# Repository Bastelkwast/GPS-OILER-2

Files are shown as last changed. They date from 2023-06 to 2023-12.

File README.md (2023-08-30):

# GPS-Oiler-2

Neue Firmware 2.8!!

Änderungen:

- Bug mit der Steuerung des Ölsymbols beseitigt.

- Es kann gewählt (im Interface) werden, ob und wie viele Pumpimpulse zu beginn der Fahrt erzeugt werden (Initial Ölung).
  Die Änderung ist erst nach einem Neustart des Oilers übernommen.

Ich bin gerade dabei die Seite umzubauen damit sie übersichtlicher wird.
Dafür benötige ich noch etwas Zeit.
Ich bitte um Verständnis.

## [Beschreibung](docs/Beschreibung/README.md)

## [Nachbau](docs/Nachbau/README.md)

## [Vorkenntnisse](docs/Vorkenntnisse/README.md)

## [Firmware Version 2.7](docs/Firmware_2.7/README.md)

## [Mainboard Rev. 5](docs/Mainboard_Rev5/README.md)

## [Bin Datei aufspielen](docs/Firmware_BIN/README.md)

## [Einbauvorschlag](docs/Tracer_900GT/README.md)

Bei Fragen einfach eine Mail an mich: GPS-Kettenoiler@web.de

Ich werde Versuchen sie zeitnah zu Beantworten.

Über eine Information mit euren Erfahrungen würde ich mich sehr freuen.

Nur so kann ich den Oiler verbessern!

Wenn ihr mir Bilder oder Anregungen von eurem Einbau zukommen lasst, und ihr es wünscht, werde ich sie auch anderen zur Verfügung stellen.

Vielleicht wird es dadurch ja noch interessanter für den ein oder anderen.

!! Der Nachbau ist ohne meiner ausdrücklichen Genehmigung nur für Private und nicht für Kommerzielle Zwecke erlaubt !!

!!Der Nachbau und Einbau des Kettenöler und seiner Bauteile erfolgt auf eigenes Risiko und Verantwortung. Ich übernehme keine Haftung!!

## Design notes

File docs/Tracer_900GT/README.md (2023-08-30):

# Einbau in einer Tracer 900 GT

## [Injector](Injector/README.md)

Die Dateien für die Gedruckten und Gefrästen Teile findet ihr im Ordner docs/Tracer_900GT/STL-Dateien

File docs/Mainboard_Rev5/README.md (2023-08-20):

# Mainboard Rev.5

## [Schaltplan](PDF/SCHALTPLAN.pdf)

## [LAYOUT](PDF/LAYOUT.pdf)

## [Bestückungsplan](PDF/BESTUECKUNGSPLAN.pdf)

Der Nachbau und Einbau des Kettenöler und seiner Bauteile erfolgt auf eigenes Risiko und Verantwortung. Ich übernehme keine Haftung.

Hier beschreibe ich den Bau des Mainboard Rev..

## Benötigte Bauteile

### Widerstände

|Bezeichnung |Beschreibung |
|---|---|
|R1 |100Ω |
|R2,R5 |10KΩ |
|R3 |2,7KΩ |
|R4 |100kΩ |
R6,R7,R8            |1KΩ                        |

### Diode

|Bezeichnung |Beschreibung |
|---|---|
|D1 |1N4007 |

### Kondensatoren

|Bezeichnung |Beschreibung |
|---|---|
|C1 |470µF/16V  RM 5mm  Elko |
|C2 |1500µF/6,3V RM 3,5  Elko |

### Transistoren

|Bezeichnung |Beschreibung |
|---|---|
|Q1 |BUZ11A |
|Q2 |BS170 |

### Sonstiges

|Bezeichnung |Beschreibung |
|---|---|
|DS R-78E50-05 |5V DC/DC Wandler |
|S1 |Kurzhubtaster 9302 |
|Controller |Wemos D1 Mini |
|GPS Modul |Neo-6M |
|OLED Display |SSD1306 Weiss I2C |
|EEPROM |24LC256-I/P |
|IC Sockel |GS 8 |
|Gummidurchführung  |5x	KDF4 |
|Klemmleiste 4fach  |AKL 059-4  Für das OLED |
|Kunststoffgehäuse  |SP 2062 SW |
|Klemmleiste 10fach |AKL 101-10 |
|Dosierpumpe |Webasto oder ähnlich |
|Kleine Schrauben |4x (2,2x4,5mm) |
|Schraube |3mm mit Mutter |
|Fotoplatine |FPE1 160X100 |

Und alles was zum Herstellen einer Leiterplatte benötigt wird.
Ich habe zum Verbinden des GPS-Modul und dem OLED mit dem Mainboard ein USB Kabel verwendet. Das war günstiger.

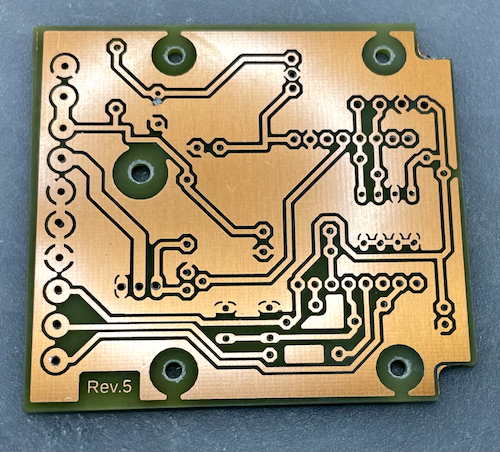
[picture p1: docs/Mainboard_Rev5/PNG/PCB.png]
PCB


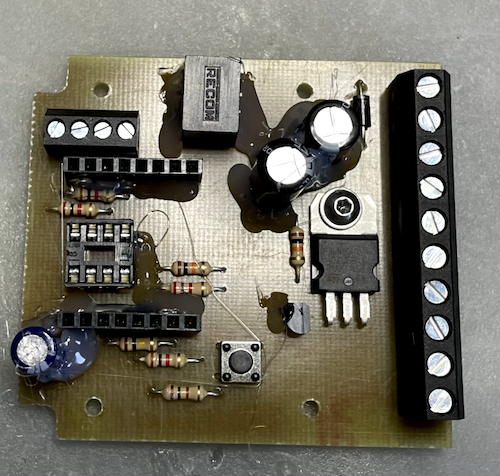
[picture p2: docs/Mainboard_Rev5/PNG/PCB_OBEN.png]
PCB OBEN


Und hier mit aufgesetztem WEMOS und DC/DC Wandler. Hatte Probleme mit der Wärmeentwicklung.

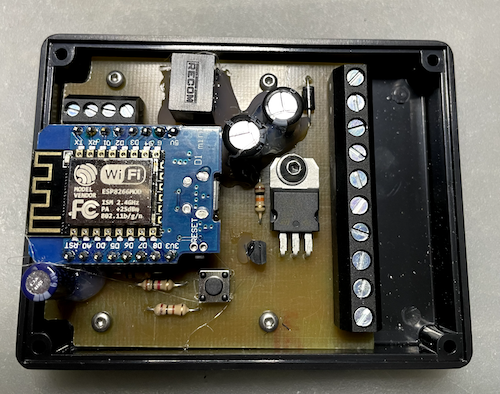
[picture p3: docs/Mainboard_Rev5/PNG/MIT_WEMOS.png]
PCB MIT WEMOS

Der Anschluss oben links ist vom OLED.

Der Taster ist zum zurücksetzen der WIFI Einstellung für den Fall das man sein WIFI Passwort vergessen haben sollte und nicht mehr rankommt.

## Anschlüsse

Masse       = Masse oder Minuspol

Klemme 15   = Zündung( Bei meiner Tracer der Stecker der Sitzbankheizung)

Pumpe       = Plus der Dosierpumpe

Pumpe       =   Minus der Dosierpumpe

3xGND       = GND für GPS,Regensensor.

VCC-2       = 3,3V für den GPS Modul

GPS-RX      = TX des GPS-Modul

Sensor      = Anschluss des Regensensor

## Vor der ersten Inbetriebnahme

Vor der ersten Inbetriebnahme unbedingt noch mal alles kontrollieren ob da alles richtig eingebaut wurde und keine Kurzschlüsse oder Unterbrechungen mehr vorhanden sind.

Wenn das erste mal Spannung angelegt wird, habe ich immer den WEMOS,OLED und das EEPROM abgezogen und erst einmal die Betriebsspannung 5V am WEMOS überprüft um zu sehen das der DC/DC Wandler auch seine 5V richtig ausgibt.

Wenn der Oiler das erste mal in Betrieb genommen wird, erkennt er daß das EEPROM noch unbeschrieben ist und beschreibt es dann mit den Werkseinstellungen automatisch.

Jetzt sollte alles funktionieren.

Es sollte jetzt etwas auf dem Display zu sehen ein. Wenn ja hat alles geklappt.

Glückwunsch!

Wenn nicht, geht die Fehlersuche los.

Sind die 3,3V am WEMOS vorhanden. Wenn nicht ist der WEMOS defekt.

Ist die 3,3V vorhanden, ist WIFI vorhanden. Wenn nicht, wurde die Firmware richtig aufgespielt?

Ist das OLED richtig angeschlossen?

Ist das OLED okay, ist GPS Empfang vorhanden? (kann bis 3 Min dauern. Dazu an einen Ort gehen wo auch Satellitenempfang möglich ist).

## Viel Erfolg beim Nachbau!

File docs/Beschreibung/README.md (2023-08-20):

# GPS-Oiler-2

## Mein GPS-OILER-2
Ich hatte mir ein neues Motorrad gekauft und wollte mir einen Mikrocontroller gesteuerten Kettenöler einbauen. 

Da ich ein Bastler bin und mit dem Arduino auch schon einiges gemacht hatte wollte ich mir einen eigenen Kettenöler bauen.

Da ich nicht an das Tachosignal gehen wollte musste ich mir etwas anderes überlegen. Einen Magneten irgendwo anzukleben und einen Reed Kontakt zu verwenden fand ich auch nicht so elegant. Aus diesem Grund habe ich mich für ein GPS Modul entschieden.

Ich wollte das ganze recht universell halten und habe das Mainboard und das GPS-Modul von einander getrennt. So kann man das Mainboard an einem Platz installieren wo kein Sat-Empfang möglich ist.

Um zu sehen ob alles vernünftig funktioniert habe ich dem Kettenöler ein kleines 0,96“ OLED Display spendiert das mir alle notwendigen Informationen anzeigt wie Geschwindigkeit, Füllstand des Öltank, bereits gefahrene km seit dem befüllen des Öltank, Richtung, Anzahl der empfangenen Satelliten, ob er gerade ölt, ob der Regenmodus aktiviert ist.

Das die Kette auch bei Regen entsprechend geölt wird habe ich einen Regenmodus eingebaut. Für die Regenerkennung benutze ich einen Regensensor der sich unter dem Bugspoiler befindet. 
Eine Individuelle Anpassung der Schwellwerte des Sensor ist im WEB Interface möglich.

Als Ölpumpe benutzte ich den Nachbau einer Webasto Dosierpumpe die 50 Pumpimpulse / ml benötigt. Es kann auch eine andere Dosierpumpe verwendet werden, die Parameter können leicht angepasst werden.

Damit ich den Kettenöler auch bedienen kann habe ich mich für den ESP 8266 Wemos entschieden. Der hat eine höhere Taktfrequenz als ein Arduino und ein WIFI Modul ist auch schon on Board. Somit habe ich für die Bedienung ein Web Interface gebaut und kann mit jedem WIFI fähigen Gerät sämtliche Einstellungen am Kettenöler vornehmen und Informationen abrufen die nicht auf dem OLED angezeigt werden. Dadurch bin ich nicht an Android oder Apple gebunden und benötige auch keine Apps dafür.

Das WIFI wird nach einer vorgegebenen Zeit abgeschaltet. Danach ist das WEB Interface bis zum nächsten Einschalten für niemanden mehr erreichbar.

Da der Wemos keinen eingebauten EEPROM besitzt kam auch ein externer EEPROM für die Speicherung aller Einstellungen und Werte zum Einsatz.

Um das Öl auf die Kette zu bekommen und ich so wenig wie möglich vom Kettenöler sehen wollte bin ich an das vordere Kettenrad gegangen und habe dafür einen Dual Injektor gebaut.

Für den Fall das der GPS Empfänger ausfällt habe ich einen Notbetrieb eingebaut der nach dem Einschalten nach einer eingestellten Zeit automatisch Aktiviert wird und eine vorgegebene Geschwindigkeit annimmt bis wieder Satellitenempfang vorhanden ist. 

Sollte der Satellitenempfang unterbrochen werden wie z.B. durch einen Tunnel, wird die letzte Geschwindigkeit so lange beibehalten bis wieder Satellitenempfang vorhanden ist.

Da der GPS-Kettenöler über Zündung (Klemme15) mit Spannung versorgt wird, kann auch keine Fehlfunktion eine Entladung der Batterie verursachen.

Ich habe zwei Startbildschirme eingebaut.
In 1. Startbildschirm wird mir die SSID des Kettenöler und die IP Adresse angezeigt (nachdem ich sie mal vergessen hatte ;-) ).
Im 2. die Version des Kettenöler und die Firmware Version. Die Anzeigezeit lässt sich im Web Interface anpassen.

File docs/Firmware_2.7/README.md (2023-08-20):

# Firmware Version 2.7

Hier wird der Kettenoiler mit der Firmware 2.7 Beschrieben.

Ich habe zwei Startbildschirme eingebaut die nach dem Einschalten angezeigt werden.

In 1. Startbildschirm wird mir die SSID des Kettenöler und die IP Adresse angezeigt (nachdem ich sie mal vergessen hatte ;-).

Im 2. die Version des Kettenöler und die Firmware Version.

Die Anzeigezeit lässt sich im Web Interface anpassen.

## Das OLED Display

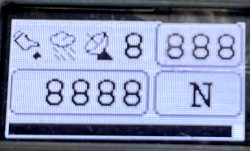
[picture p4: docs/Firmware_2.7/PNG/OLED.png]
OLED


### Erklärung obere Reihe von links nach rechts

-Die Kette wird gerade geölt.

-Regenmodus ist Aktiv.

-Satellitenempfang vorhanden.

-Anzahl der empfangenen Satelliten. Wenn die Anzahl der empfangenen Satelliten die Anzahl 9 übersteigt wird die Zehnerstelle anstelle des Satelliten Symbol angezeigt.

-Die ermittelte Geschwindigkeit.

### Untere Reihe•

-Gefahrene km seit dem letzten auffüllen.

-Die Himmelsrichtung in die man fährt

-Ganz unten befindet sich ein Balken der den berechneten Füllstand des Öltanks anzeigt.

### Browser

Um mit einem Browser das Web Interface nutzen zu können muss man als erstes das WIFI des Kettenölers in den Einstellungen des WIFI fähigen Gerät auswählen.

Anschließend gibt man im Browser die IP Adresse „192.168.4.1“ ein.

Jetzt sollte das Interface wie unten beschrieben zu sehen sein.

### Das Web Interface

Mit Hilfe des Web Interface kann man die Einstellungen des Kettenölers anzeigen lassen und wenn nötig anpassen.

## Startseite des Web Interface

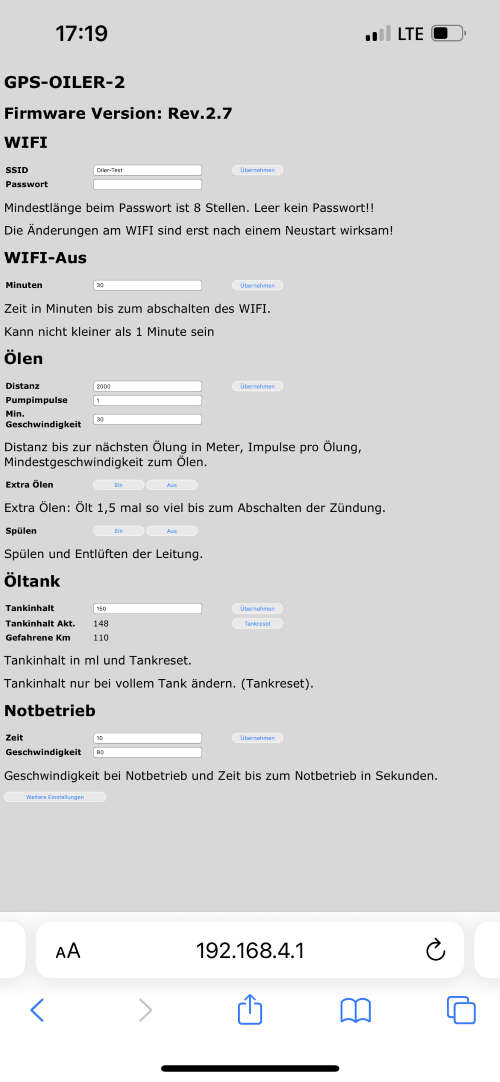
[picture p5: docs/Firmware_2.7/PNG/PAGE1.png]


### Wifi

Einstellung der SSID Kennung Einstellung des WIFI Passwort.

Wenn das Feld „Passwort“ keinen Eintrag hat, wird kein Passwort abgefragt.

### WIFI- Aus

Die Zeit in Minuten nach dem Einschalten und der letzten Eingabe über das Web Interface bis WIFI automatisch abgeschaltet wird.

### Ölen

Die Distanz zwischen den einzelnen Ölungen. Anzahl der Pumpimpulse pro Ölung.
Mindestgeschwindigkeit unter der das Ölen verhindert wird.

### Extra Ölen

Hier kann ich extra Ölen aktivieren. Durch das aktivieren wird der Abstand der einzelnen Ölungen um den Faktor 1,5 reduziert für den Fall das man z.b. auf Sandwegen unterwegs sein sollte. Das extra Ölen wird mit dem abschalten der Zündung automatisch deaktiviert.
Spülen
Der Kettenöler pumpt so lange bis Spülen wieder abgewählt oder die Zündung abgeschaltet wird.

### Öltank

Tankinhalt in ml.Aktueller Tankinhalt in ml.Gefahrene km seit „Übernehmen“ oder „Tankreset“.

### Notbetrieb

Wenn kein Sat-Empfang vorhanden ist, Zeit in Sekunden bis der Notbetrieb aktiviert wird. Bleibt so lange aktiv bis wieder Satellitenempfang vorhanden ist.
Angenommene Geschwindigkeit für den Notbetrieb.

### Weitere Einstellungen ( zweite Seite des Web Interface )

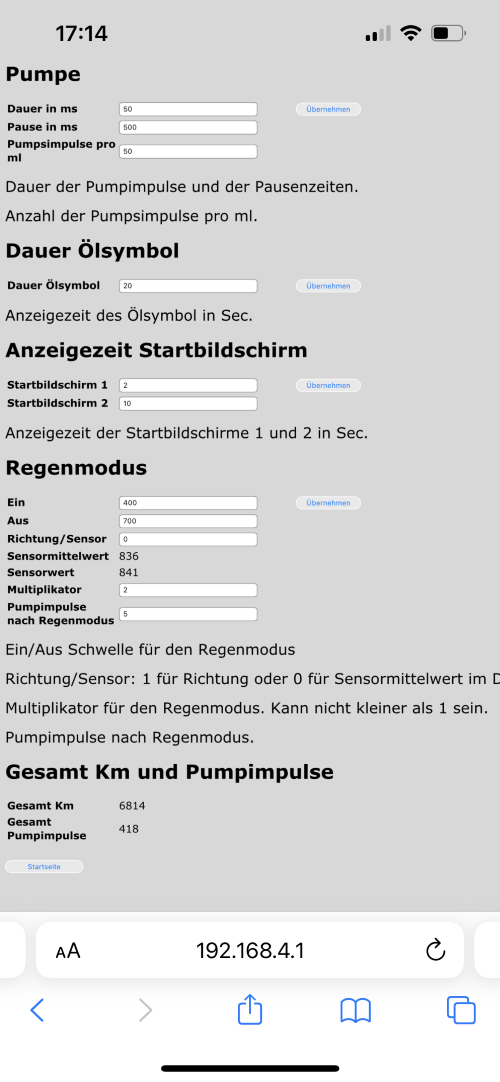
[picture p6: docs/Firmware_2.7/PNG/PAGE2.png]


### Pumpe

Dauer in Millisekunden wie lange die Pumpe mit Spannung versorgt wird.
Dauer in Millisekunden wie lange die Pause zwischen zwei Pumpimpulsen mindestens sein soll.
Anzahl der Pumpimpulse die für 1 ml benötigt werden.

### Dauer Ölsymbol

Zeit in Sekunden wie lange das Ölen Symbol im OLED Display angezeigt wird.

### Anzeigezeit Startbildschirm

Zeit in Sekunden wie lange der Startbildschirm 1 nach dem Einschalten angezeigt werden soll.
Zeit in Sekunden wie lange der Startbildschirm 2 nach dem Einschalten angezeigt werden soll.

### Regenmodus

#### Ein

Schwellwert bei dem der Regenmodus aktiviert werden soll.

#### Aus

Schwellwert bei dem der Regenmodus wieder deaktiviert werden soll.
Der Schwellwerte für das Aktivieren des Regenmodus muss niedriger als der Schwellwert für das Deaktivieren des Regenmodus sein.

#### Richtung/Sensor

Hier kann ich wählen was ich im OLED angezeigt haben möchte. Entweder die Richtung in die ich gerade fahre oder der Wert des Regensensor. Das habe ich eingebaut damit ich einen besseren überblick von Regensensor haben kann.

#### Sensormittelwert

Hier wird der errechnete Sensormittelwert angezeigt.

#### Sensorwert

Aktueller Sensorwert.

#### Multiplikator

Multiplikator wie viel mehr bei Regen geölt werden soll. Er kann nicht kleiner als 1 eingestellt werden.

#### Pumpimpulse bei Regenmodus

Anzahl der Pumpimpulse nach dem Regenmodus. Dadurch soll das Öl das durch den Regen abgespült wurde wieder auf die Kette gebracht werden.

#### Gesamt Km und Pumpimpulse

Gesamt km

Hier werden die km angezeigt die insgesamt mit dem Kettenöler gefahren wurden.

Gesamt Pumpimpulse

Hier werden die Pumpimpulse angezeigt die insgesamt mit dem Kettenöler gepumpt wurden.

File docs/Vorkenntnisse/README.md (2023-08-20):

## Vorkenntnisse

Es sind schon etwas Kenntnisse erforderlich um diesen Kettenöler nachzubauen.

Man sollte wissen was ein Widerstand ist und welche Wert er hat. 

Was ein Kondensator, Transistor usw. ist.

Man sollte sich auch schon mal mit dem Arduino beschäftigt haben und wissen was ein WEMOS ist, damit man sich mit der Arduino IDE (Programmier Tool) schon etwas auskennt.

Ein 12V Netzteil ist auch ganz nett um schon mal den Probelauf machen zu können. 

Löten sollte auch kein Problem darstellen.

Da die Leiterplatte selbst hergestellt wird, sollte man da auch schon Erfahrung gesammelt haben.

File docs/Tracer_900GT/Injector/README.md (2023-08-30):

# Injector

## Der Injektor an meiner Tracer 900 GT

### !!Der Nachbau und Einbau des Injektor und seiner Bauteile erfolgt auf eigenes Risiko und Verantwortung.

### Ich übernehme keine Haftung

Da ich so wenig wie möglich vom Kettenöler sehen wollte habe ich mich dafür entschieden den Injektor an das vordere Kettenrad zu setzen.

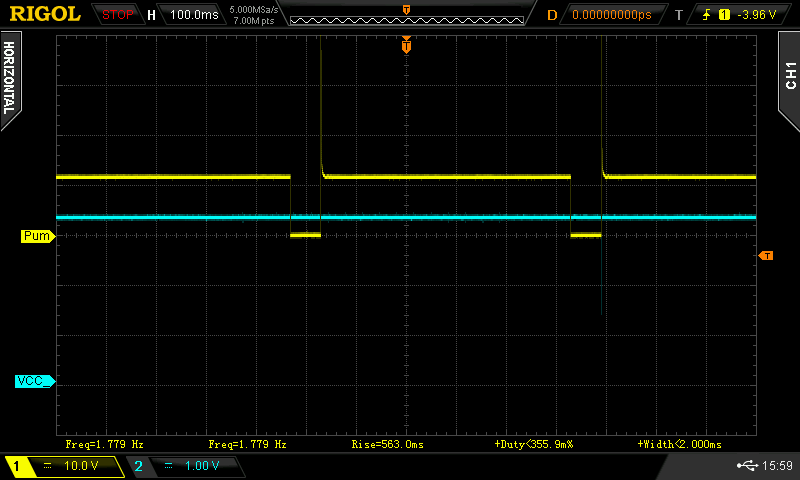
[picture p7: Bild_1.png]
Bild_1


## Das Halteblech für den Injector

Das Blech habe ich mit Hilfe einer CNC Fräse hergestellt.

Das Halteblech habe ich auf der Kettenseite etwas abgeschrägt damit die Kette auch wirklich nichts hat um daran hängen zu bleiben.

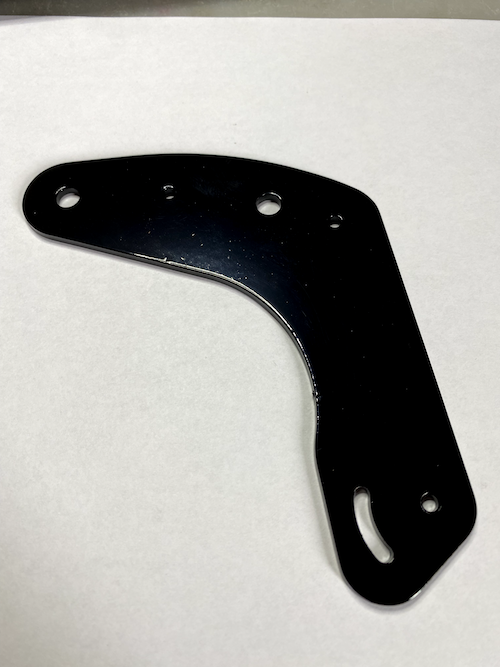
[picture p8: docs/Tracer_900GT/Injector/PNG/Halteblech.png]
Halteblech


Hier sind die Haltenasen die ich mit einem 3D Drucker gedruckt habe

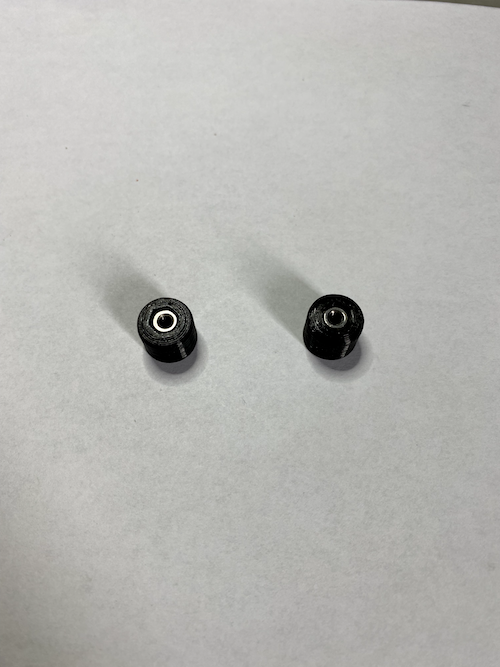
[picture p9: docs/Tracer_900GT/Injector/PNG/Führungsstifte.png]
Führungsstifte


Blech mit Haltenasen

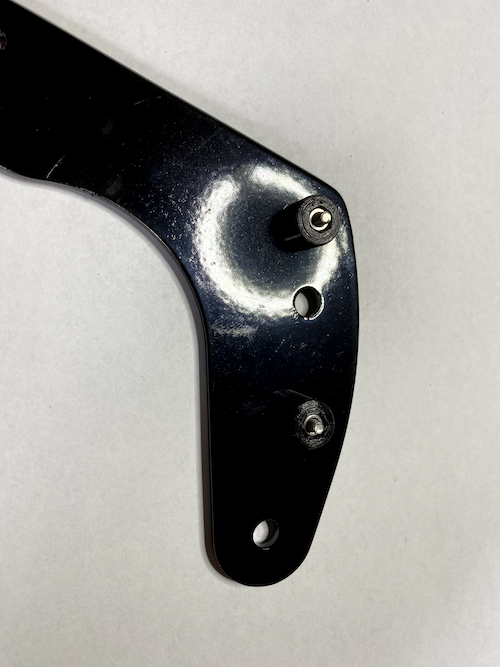
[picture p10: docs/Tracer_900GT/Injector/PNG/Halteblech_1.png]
Halteblech_1


Kettenführung

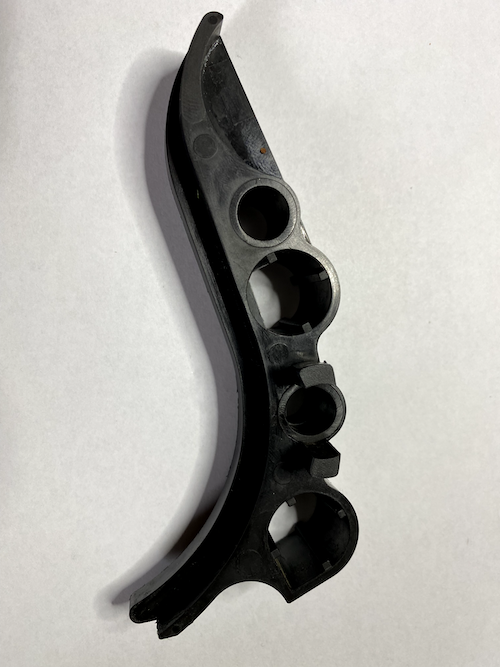
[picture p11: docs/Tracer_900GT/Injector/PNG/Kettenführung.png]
Kettenführung


Blech mit Kettenführung

Hier sind die beiden Führungsstifte und die Kettenführung mit dem Halteblech aus 3mm  Aluminium miteinander verbunden.
Dadurch wird später das ganze erst eimal in Position gehalten bis die Abdeckung das ganze zusammen hält.

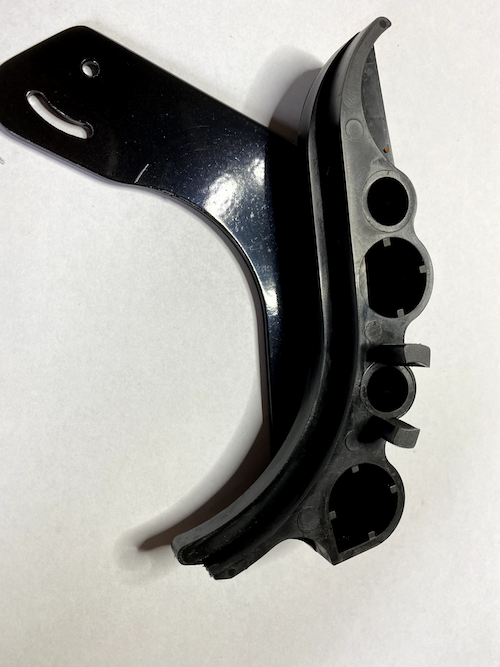
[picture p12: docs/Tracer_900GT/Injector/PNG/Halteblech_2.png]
Halteblech_2


Injector

Der aus PETG gedruckte Dual Injektor.

In den Injektorblock habe ich zwei Stückchen Silikonschlauch eingesetzt. Da hinein kommen dann die Röhrchen die dadurch im Block gehalten werden und das ganze schön Abgedichten.

Die Röhrchen habe ich aus dem Modellbau Zubehör (Bowdenzug).

Für den Schlauchanschluss dient ein stück Messingrohr.

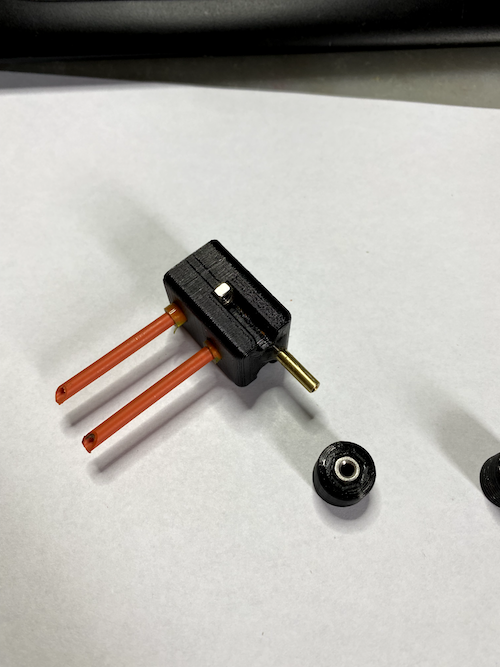
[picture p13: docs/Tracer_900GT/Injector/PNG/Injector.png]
Injector


Blech mit Injector

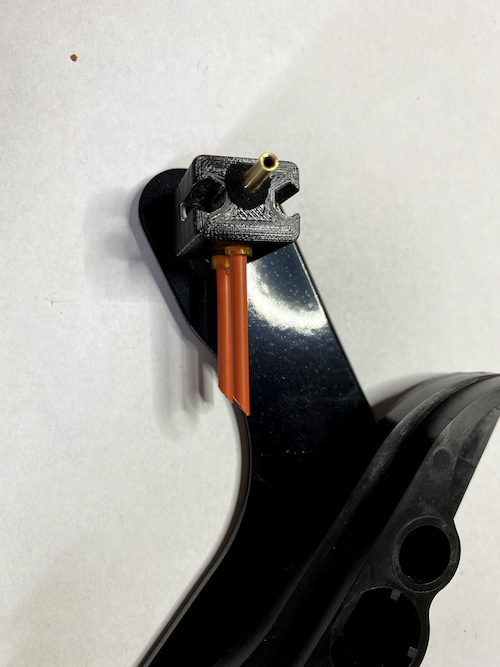
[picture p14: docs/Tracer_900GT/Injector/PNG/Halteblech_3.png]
Halteblech_3


Halteblech mit Injector am Motorrad angesetzt

Durch die Langlöcher kann der Injector optimal justiert werden.

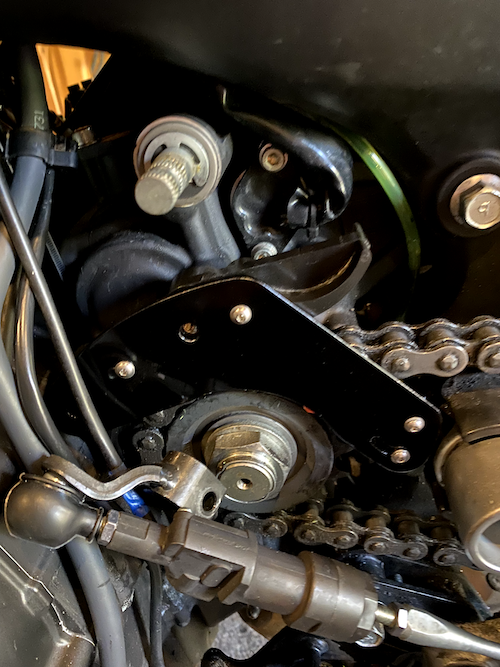
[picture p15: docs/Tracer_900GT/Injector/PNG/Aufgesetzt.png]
Aufgestetzt


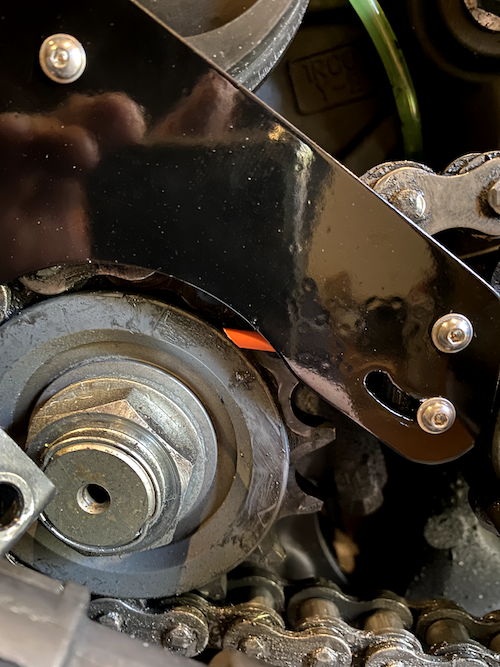
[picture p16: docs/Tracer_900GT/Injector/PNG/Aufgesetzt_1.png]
Aufgesetzt_1


Mit der Änderung der Kunststoffröhrchen wird das Öl besser auf die Kette übertragen.

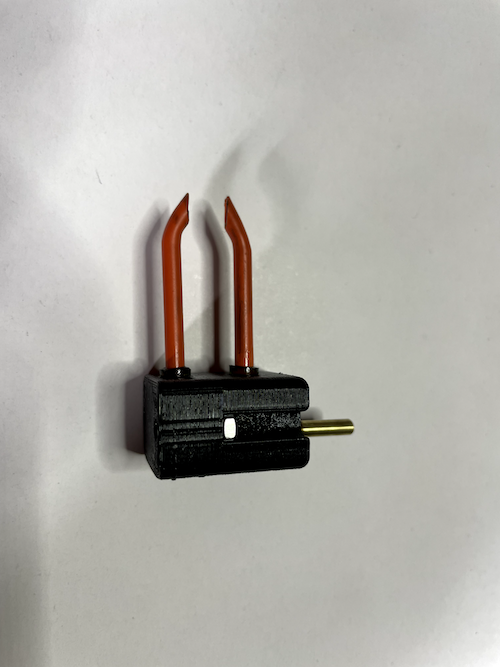
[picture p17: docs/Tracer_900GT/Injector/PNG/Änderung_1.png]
Änderung_1


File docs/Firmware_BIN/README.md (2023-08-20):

# BIN Datei aufspielen

Nicht jeder kennt sich mit VSC aus.

Deshalb habe ich nach einer anderen Möglichkeit gesucht die Firmware auf den WEMOS aufzuspielen.

In diesem Video erklärt Fabsenet sehr Verständlich wie man die BIN Datei (Firmware) auf den Wemos bekommen kann.

Nochmal vielen Dank für das super Video.

link: www.youtube.com/watch?v=TrDgyIsYsx4

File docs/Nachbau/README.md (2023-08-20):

## Nachbau

Ich habe vor hier alles was für einen erfolgreichen Nachbau notwendig ist zur Verfügung zu stellen.

Somit befindet sich hier:

- der Kompilierte Code sowie eine Anleitung die es ermöglichen soll den Wemos zu beschreiben.
- Schaltplan
- Das Layout der Leiterplatte.
- Bestückungsplan.
- Beschreibungen für das Mainboard, GPS-Empfänger, OLED Display, Injektor usw.
- stl Dateien für den 3D Drucker, um die Gehäuse und Halterungen die ich entworfen hatte,

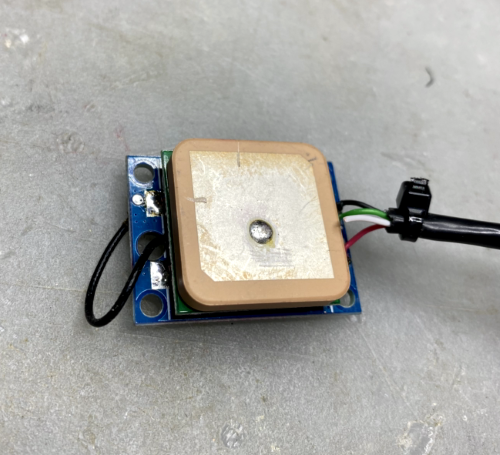
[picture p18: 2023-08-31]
docs/Tracer_900GT/PNG/GPS_3.png

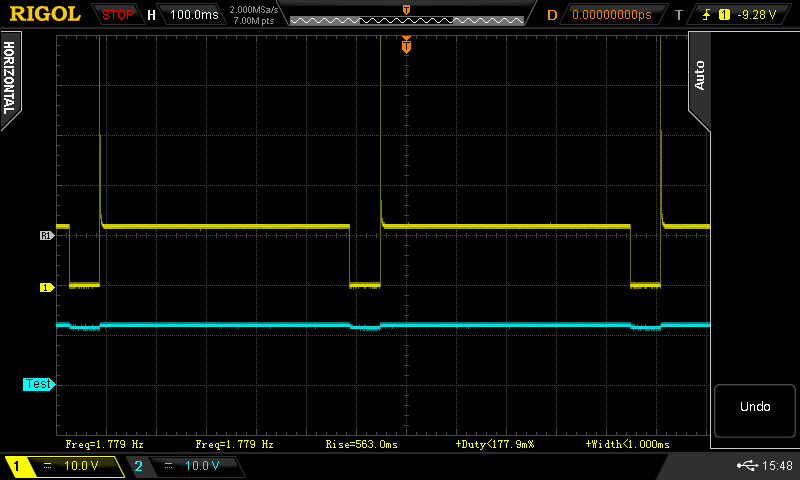
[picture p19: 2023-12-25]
DS2_20230811154808.png

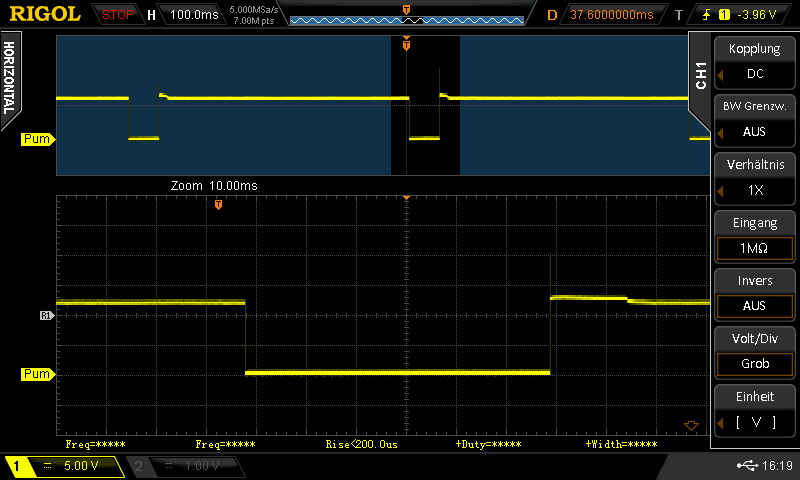
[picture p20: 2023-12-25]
DS2_20230811161950.png

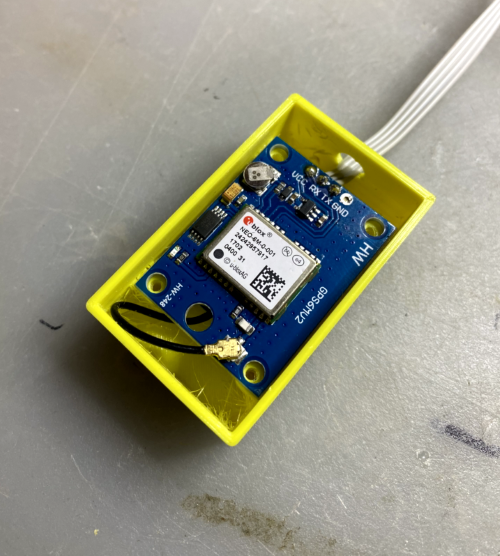
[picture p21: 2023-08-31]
docs/Tracer_900GT/PNG/GPS_2.png

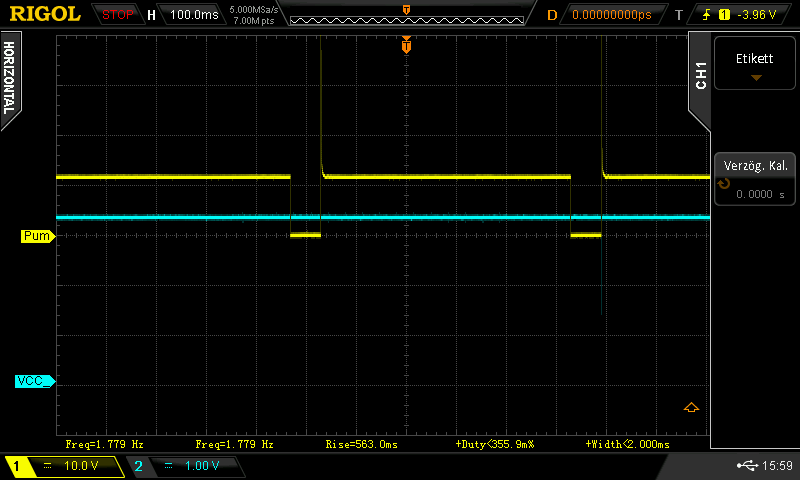
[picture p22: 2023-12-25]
DS2_20230811155905.png

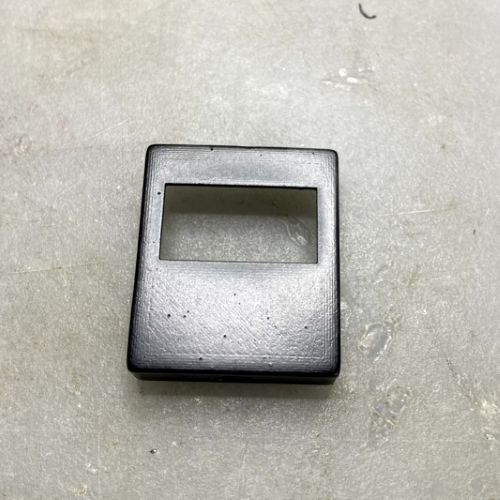
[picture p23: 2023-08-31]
docs/Tracer_900GT/PNG/OLED_Gehäuse.png

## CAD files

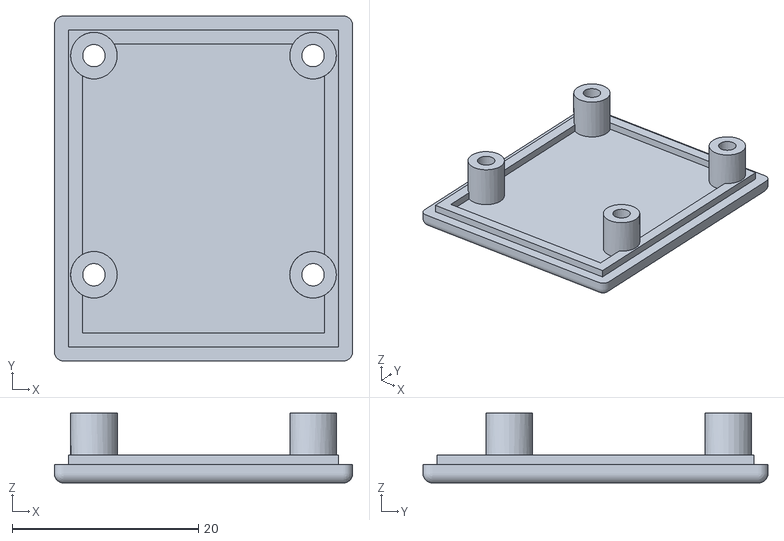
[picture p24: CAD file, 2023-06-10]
docs/Tracer_900GT/STL-Dateien/Display Tracer 900/OLED-Gehaeuse-Deckel.stl
32.0 x 37.0 x 7.50

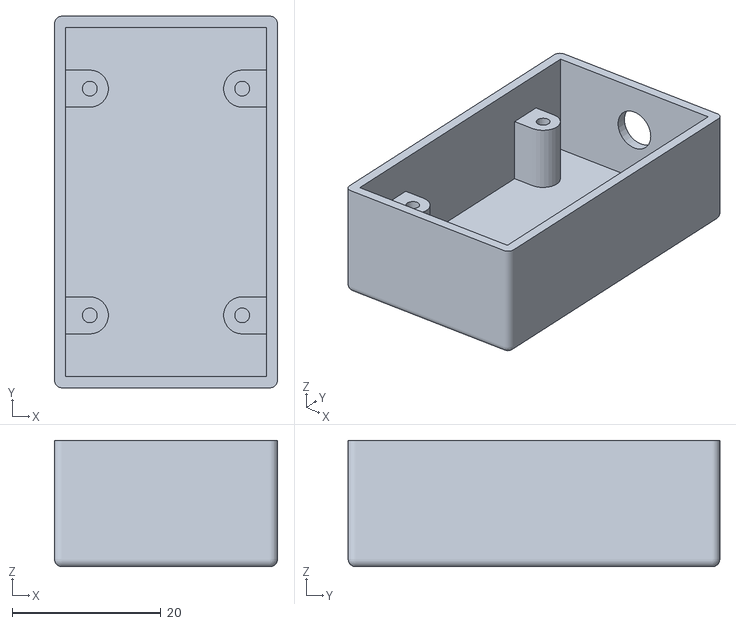
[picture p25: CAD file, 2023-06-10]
docs/Tracer_900GT/STL-Dateien/GPS/GPS-Gehaeuse.stl
30.0 x 50.0 x 17.0

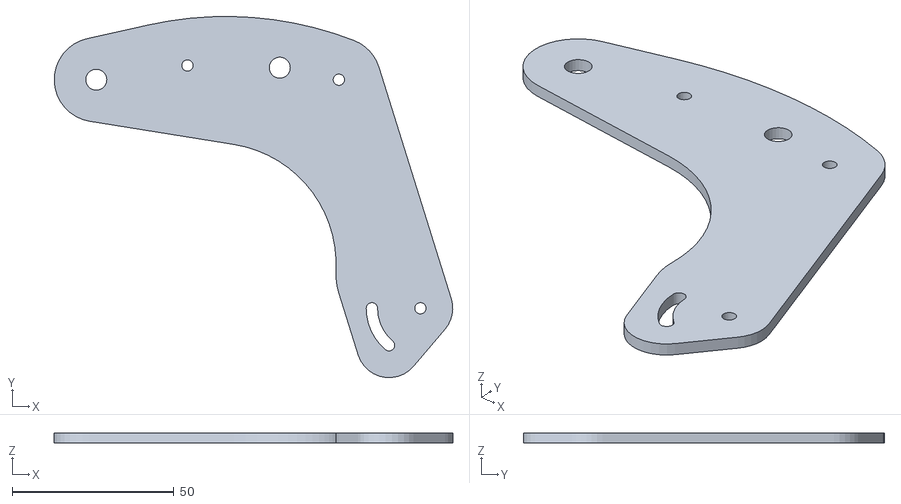
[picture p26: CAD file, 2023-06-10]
docs/Tracer_900GT/STL-Dateien/Injektor Vorne Tracer 900/Träger_Injektor_Vorne.stl
123.2 x 111.6 x 3.00

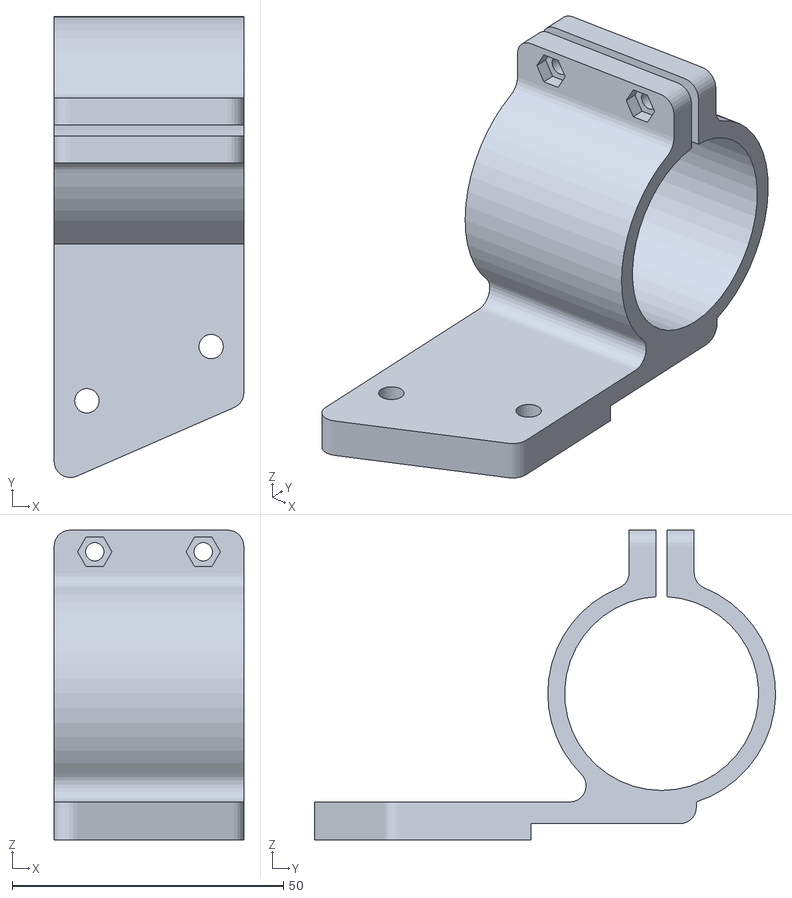
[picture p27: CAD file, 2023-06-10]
docs/Tracer_900GT/STL-Dateien/Pumpe Tracer 900/Halter Pumpe Links.stl
35.0 x 85.0 x 57.1

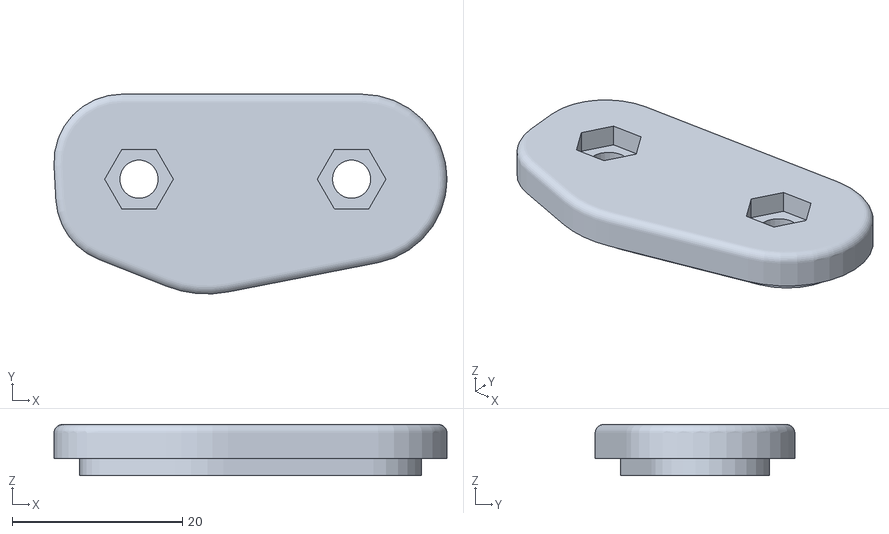
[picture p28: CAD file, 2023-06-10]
docs/Tracer_900GT/STL-Dateien/Tank Tracer 900/Lager_Rechts.stl
46.2 x 23.5 x 6.00

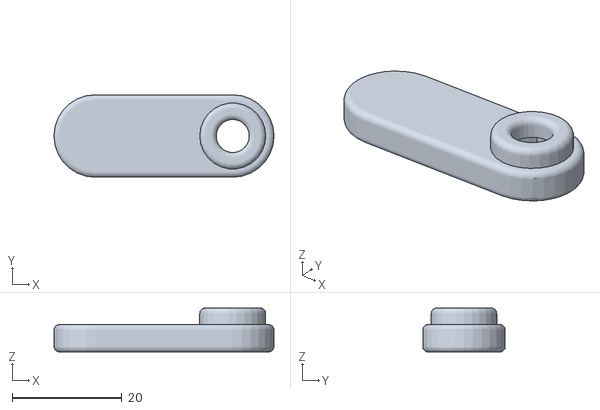
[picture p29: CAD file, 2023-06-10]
docs/Tracer_900GT/STL-Dateien/Display Tracer 900/Montierhilfe Rev.2.stl
40.0 x 15.0 x 8.00

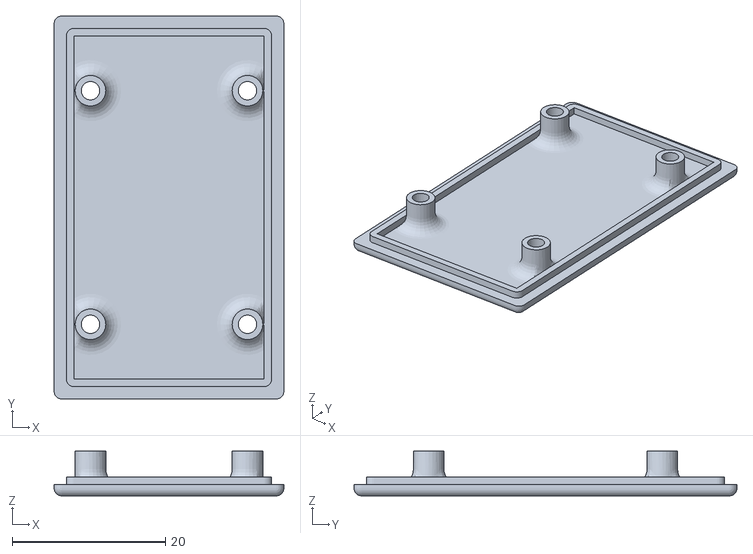
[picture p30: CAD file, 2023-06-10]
docs/Tracer_900GT/STL-Dateien/GPS/GPS-Gehaeuse_Deckel.stl
30.0 x 50.0 x 5.85

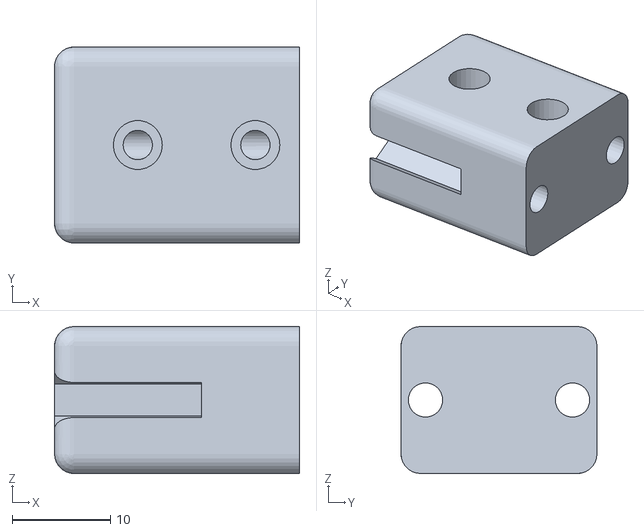
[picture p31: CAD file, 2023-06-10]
docs/Tracer_900GT/STL-Dateien/Injektor Vorne Tracer 900/Injektorblock_Vorne.stl
25.0 x 20.0 x 15.0

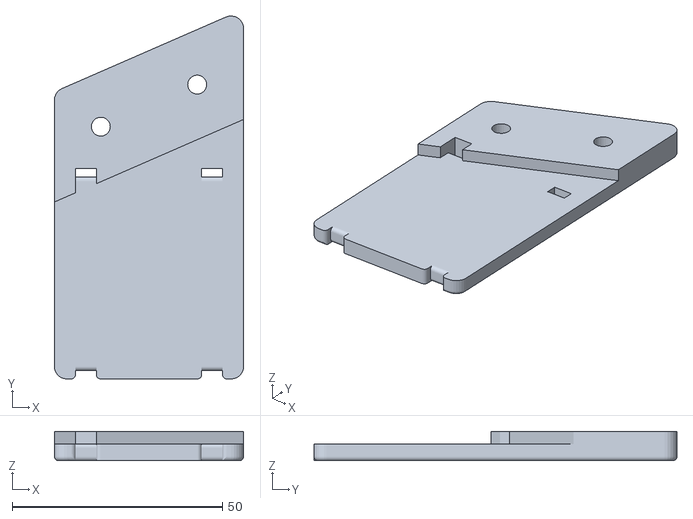
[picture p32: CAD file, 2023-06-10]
docs/Tracer_900GT/STL-Dateien/Tank Tracer 900/Halter Tank Rechts.stl
45.0 x 86.3 x 7.00

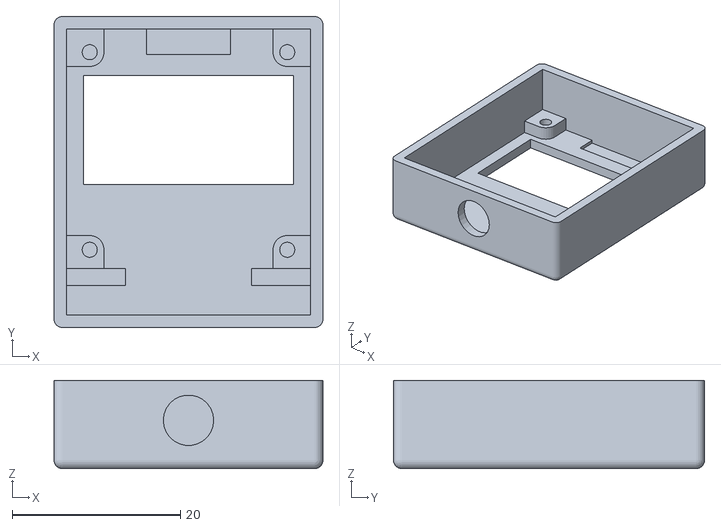
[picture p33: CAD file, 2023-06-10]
docs/Tracer_900GT/STL-Dateien/Display Tracer 900/OLED-Gehaeuse.stl
32.0 x 37.0 x 10.5

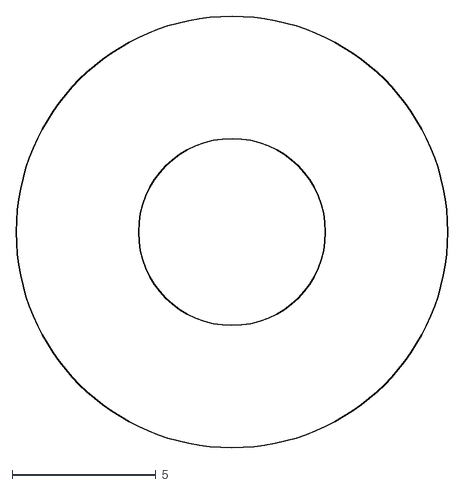
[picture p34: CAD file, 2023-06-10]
docs/Tracer_900GT/STL-Dateien/Injektor Vorne Tracer 900/Distanzscheibe_unten.dxf
15.0 x 15.0

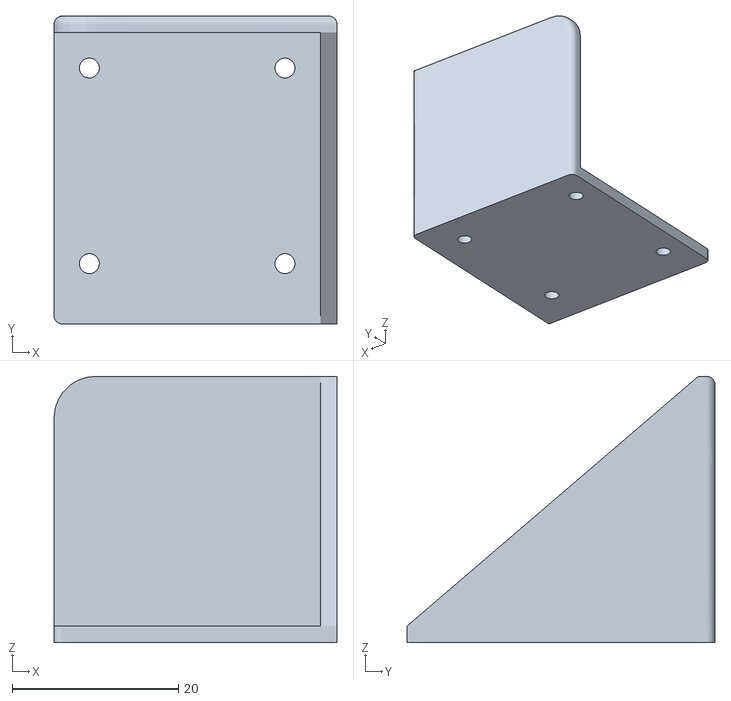
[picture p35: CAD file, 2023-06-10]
docs/Tracer_900GT/STL-Dateien/Display Tracer 900/Sonnenblende_Display.stl
34.0 x 37.0 x 32.0

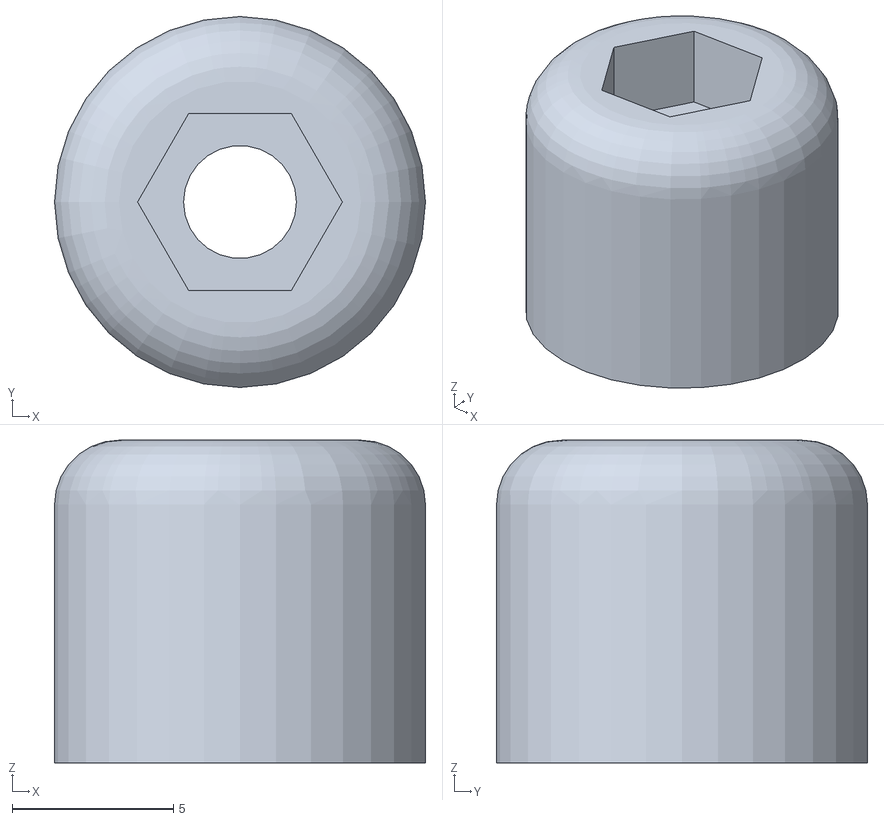
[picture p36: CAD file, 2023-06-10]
docs/Tracer_900GT/STL-Dateien/Injektor Vorne Tracer 900/Träger_Injektor_Vorne_Führungsstift.stl
11.5 x 11.5 x 10.0

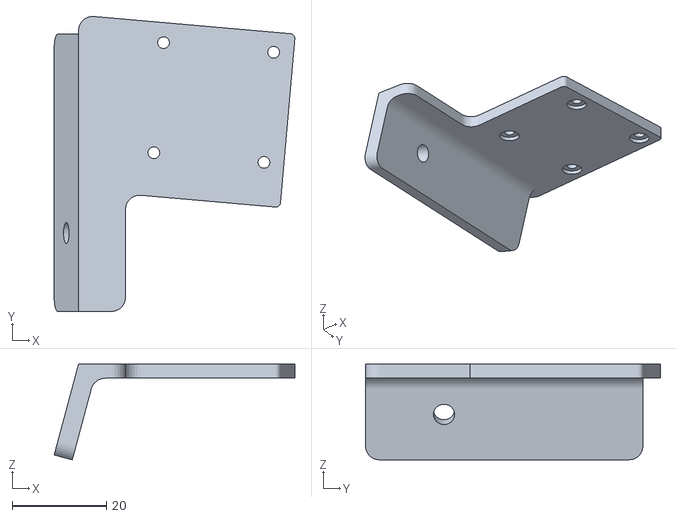
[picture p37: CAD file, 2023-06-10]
docs/Tracer_900GT/STL-Dateien/Display Tracer 900/Traeger-OLED-Gehaeuse-Tracer.stl
51.2 x 62.7 x 20.4

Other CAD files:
docs/Tracer_900GT/STL-Dateien/Pumpe Tracer 900/Lager_Links.stl

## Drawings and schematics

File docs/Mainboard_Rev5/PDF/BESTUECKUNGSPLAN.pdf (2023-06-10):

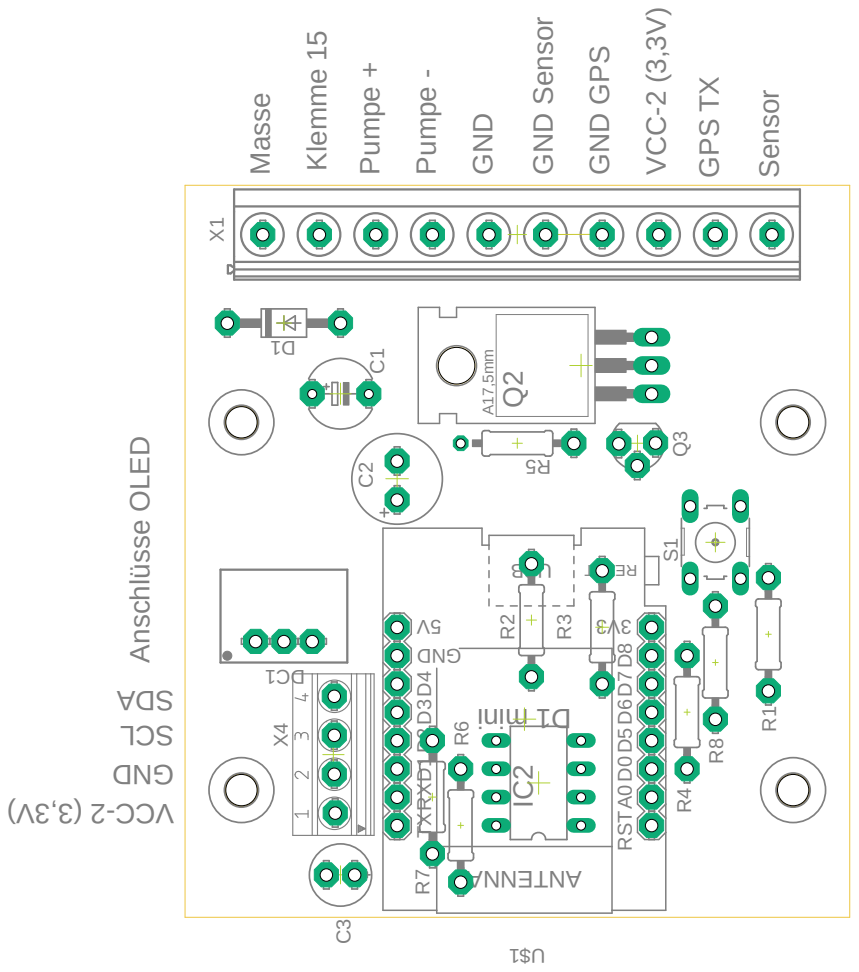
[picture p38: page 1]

GND Masse Klemme 15 Pumpe + Pumpe - GND GND Sensor GND GPS VCC-2 (3,3V) GPS TX Sensor

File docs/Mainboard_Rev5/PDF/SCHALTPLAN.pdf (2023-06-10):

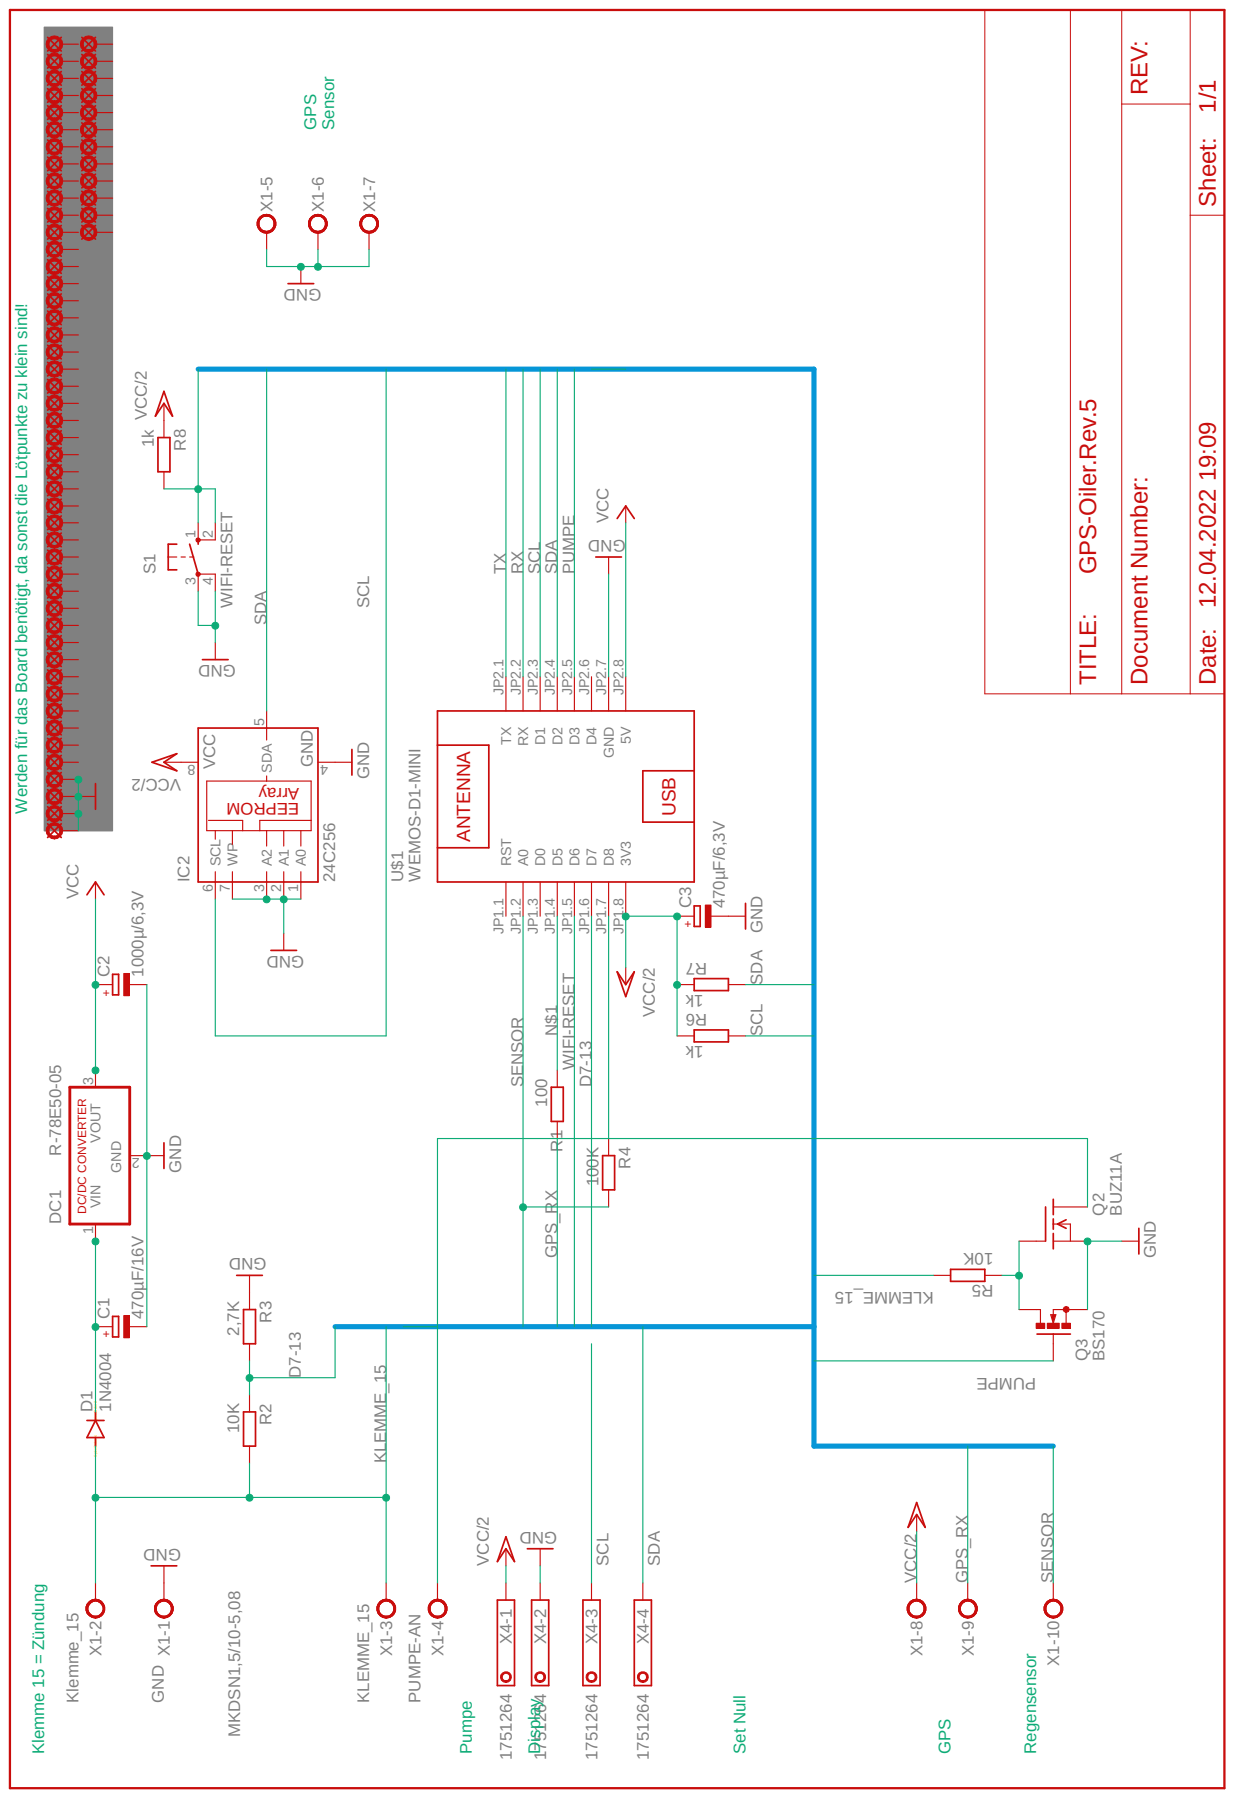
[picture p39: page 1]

KLEMME_15 SENSOR SENSOR D7-13 D7-13 N$1 TXRX WIFI-RESET WIFI-RESET Date: Sheet: REV: TITLE: Document Number: 12.04.2022 19:09 1/1 GPS-Oiler.Rev.5 USB ANTENNA Array

EEPROM + DC/DC CONVERTER + + Klemme 15 = Zündung Pumpe Display Set Null GPS Regensensor GPS Sensor Werden für das Board benötigt, da sonst die Lötpunkte zu klein sind!

GND VCC/2 VCC/2 VCC/2 100K WEMOS-D1-MINI VCC

VCC/2 GND 1k VCC/2 GND 1000µ/6,3V

R5 R4 RST JP1.1 A0 JP1.2 D0 JP1.3 D5 JP1.4 D6 JP1.5 D7 JP1.6 D8 JP1.7 3V3 JP1.8 TX JP2.1 RX JP2.2 D1 JP2.3 D2 JP2.4 D3 JP2.5 D4 JP2.6 GND JP2.7 5V JP2.8 U$1 R1 8 VCC GND 4 SCL 6 SDA 5 A0 1 A1 2 A2 3 WP 7 IC2 R8 C2 GND VIN 1 VOUT 3 2 DC1

PUMPE PUMPE GPS_RX GPS_RX SDA SDA SDA SDA SCL SCL SCL SCL KLEMME_15 KLEMME_15

SpiceOrder 1 SpiceOrder 2 1N4004 VCC GND BUZ11A GND

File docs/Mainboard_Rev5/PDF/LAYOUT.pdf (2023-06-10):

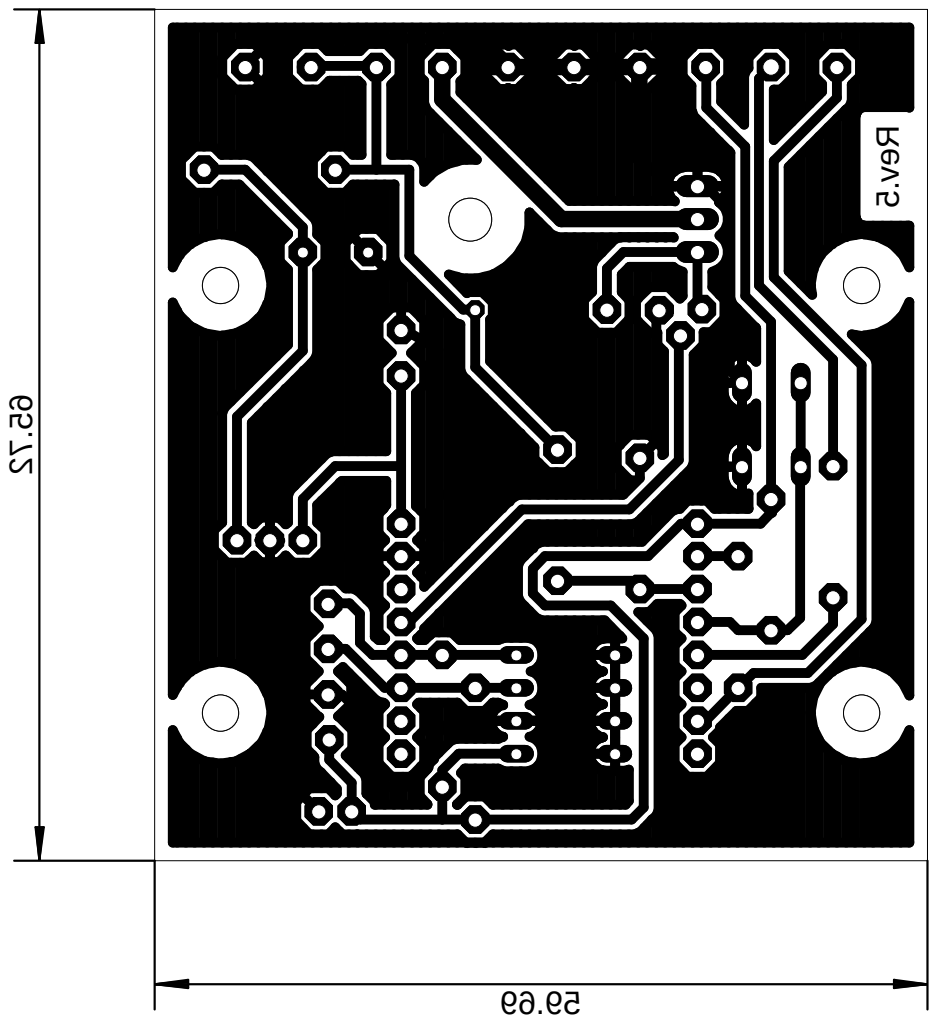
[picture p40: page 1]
Rev.5 65.72

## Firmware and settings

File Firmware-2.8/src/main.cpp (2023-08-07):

char Rev_OILER[] = "GPS-OILER-2"; // Bezeichnung der Hardware
char firmware_Vers[] = "Rev.2.8"; // Aktuelle Firmwareversion

// EEPROM I2C Addresse vom Display
#define EEPROM_I2C_ADDRESS 0x50

#include <Arduino.h>                  //
#include <Adafruit_GFX.h>             //
#include <Adafruit_SSD1306.h>         // Für das OLED
#include <TinyGPS++.h>                // Für das GPS
#include <SoftwareSerial.h>           // Wird für den Serial für den GPS-Empfänger benötigt
#include <Fonts/FreeMonoBold12pt7b.h> // Schriftart für das OLED
#include <Fonts/FreeMono9pt7b.h>      // Schriftart für das OLED
#include <EEPROM.h>                   // Für das EEPROM
#include <Wire.h>                     // Für I2C
#include <ESP8266WiFi.h>              // Für WIFI
#include <ESP8266WebServer.h>         // Für WIFI

static const int RXPin = 14;          // Für Software Serial
static const uint32_t GPSBaud = 9600; // Baudrate für Software Serial

Adafruit_SSD1306 display(128, 64); // Definition für das OLED
TinyGPSPlus gps;                   //
SoftwareSerial GPS_serial(RXPin);  // The serial connection to the GPS device

const int oilPin = 0;       // Pin an dem die Pumpe angesteuert wird
const int LedPin = 2;       // LED auf der Platine
const int regenSensor = A0; // Pin für Regensensor
const int Wlan_Reset = 12;  // Taster zum Resetten des AP, Setzt ssid auf "OILER" und Passwort wird deaktiviert
const int U_Sensor = 15;    // Spannung für den Regensensor
const int U_VCC2 = 13;      // Prüft die Spannung an Klemme 15

// Variable für die Seriellen Eingabe
String inputString = ""; // a String to hold incoming data

// Variablen die über den Serial Monitor geändert werden können
String Vari_zeit_pumpe_ein = "Zeit Pumpdauer:";
String Vari_zeit_pumpe_pause = "Zeit Pumppause:";
String Vari_oilsymbol_Zeit = "Zeit Ölsymbol:";
String Vari_zeit_bis_notbetrieb = "Zeit bis Notbetrieb:";
String Vari_Not_geschwindigkeit = "Geschwindigkeit Notbetrieb:";
String Vari_pump_nach_Regen = "Pumpstoesse nach Regen:";
String Vari_Gefahrene_km = "Gefahrene Km:";
String Vari_Gefahrene_km_Ges = "Gesamt Km:";
String Vari_pumpDistanz = "Pumpdistanz:";
String Vari_anzahl_Pump = "Anzahl Pumpimpulse:";
String Vari_minGeschwindigkeit = "Min. Geschwindigkeit:";
String Vari_tankinhalt_max = "Max.Tankinhalt:";
String Vari_Start_disp_1 = "Startbildschirm 1:";
String Vari_Start_disp_2 = "Startbildschirm 2:";
String Vari_pump_anzahl_Ges = "Pumpimpulse Gesamt:";
String Vari_rainMulti = "Regen Multiplikator:";
String Vari_geschwindigkeit = "Geschwindigkeit:";

// Benutzerdifinierte Variablen
int anzahl_Pump = 1;                 // Anzahl der Pumpimpulse je Ölung
int minGeschwindigkeit = 20;         // Mindestgeschwindigkeit zum Ölen
int oilsymbol_Zeit = 6;              // Zeit in Sec. wie lange das OilSymbol erscheint
int geschwindigkeit_Notbetrieb = 80; // Geschwindigkeit die angenommen wird wenn kein Sat-Empfang ist (Notbetrieb)
int zeit_bis_notbetrieb = 180;       // Zeit bis Notbetrieb in Sekunden
int zeit_pumpe_ein = 50;             // Zeit in ms wie lage die Pumpe eineschaltet ist
int zeit_pumpe_pause = 500;          // Zeit zwischen den einzelnen Pumpimpulsen
int TimeAPout = 5;                   // Zeit in Minuten bis sich der AP wieder abschaltet
int pump_nach_Regen = 5;             // Pumpimpulse wenn der Regenmodus abgeschaltet wird
int Start_disp_1 = 10;               // Zeit für Startdisplay 1 in Sec.
int Start_disp_2 = 10;               // Zeit für Startdisplay 2 in Sec.
int sw_Regensensor_ein = 500;        // Schwellwert Regenmodus ein
int sw_Regensensor_aus = 600;        // Schwellwert Regenmodus aus
int pumpDistanz = 2000;              // Abstand in m zwischen den einzelnen Ölungen
int tankinhalt_ml = 150;             // Tankinhalt in ml
int pumps_ml = 50;                   // Anzahl der Pumpimpulse pro ml
int init_pump_anzahl = 0;            // Anzahl der Pumpimpulse für die Initialölung
float rainMulti = 2.0;               // Multiplikator für Regenmodus
char ssid_ap[20] = "GPS-OILER";      // Die SSID
char password_ap[20] = "";           // alternativ :  = "12345678";
char ssid_ap_set[20] = "GPS-Oiler";  // Wird bei WLAN RESET gesetzt
char password_ap_set[20] = "";       // Wird bei WLAN RESET gesetzt / alternativ :  = "12345678";

// Funktionelle Variablen
boolean Factory_init = 0;          // Wird für die erste Inbetriebnahme verwendet
boolean Spuelen = false;           // Variable für Spülen
boolean extraOilen = false;        // Variable für extraSpülen
boolean regenmodus = false;        // Bestimmt ob Regenmodus aktiv ist
boolean oilsymbol = false;         // Status für die Anzeige des Oilsymbol
boolean speed_show_toogle = true;  // Geschwindigkeit Blinkt wenn kein Satempfang
boolean sat_empfang = false;       // Satempfang und Serielle Daten vom GPS-Modul vorhanden
boolean notbetrieb = false;        // Wird bei Notbetrieb gesetzt
boolean oilen = false;             // Wird gesetzt wenn die nächste Ölung ansteht
boolean Not_Oil_Init = false;      // Variable für die Initialölung wenn der Notbetrieb beginnt
boolean invert_Display = true;     // Display Invertieren oder nicht
boolean TimeAPout_set = false;     // Variable wird gesetzt wenn AP aus ist
boolean oled_akt = false;          // wird für das Aktualisieren des OLD benötigt
boolean HTML_Page = true;          // Seite des Web Interface
boolean stop_write_eeprom = false; // verhindert das Beschreiben des EEPRON Speichers
boolean dir_Display = true;        // Wird für die Auswahl benötigt ob die Richtung oder der Mittelwet des ADC angezeigt werder soll
byte pump_anzahl_soll = 0;         // Aktuelle Anzahl der Pumpimpulse
byte tankinhalt_Anzeige = 0;       // Wert für die Anzeige des Balken (Von 0 - 128)
byte sateliten_anzahl = 0;         // Anzahl der empfangenen Sateliten
byte action;                       // Wird für HTML benutzt
int richtung = 0;                  // Wird für die Anzeige der Richtung benötigt
int tankinhalt_Aktuell = 0;        // Wert des Aktuellen Tankinhalt
int tankinhalt_max = 150;          // Anzahl der Pumpimpulse die benötigt werden um den Tank zu leeren. Wird später berechnet.
int regenValue = 0;                // Wert der am Regensensor ermittelt wird
int regensensorMittelwert = 0;     // Ermittelter Mittelwert des Regensensor
int notbetrieb_variable = 0;       // Variable zur ermittlung des Notbetrieb.
int Gefahrene_km_Temp = 0;         // wird für das Speichern der Km benötigt
int Gefahrene_km_display = 0;      // Gefahrene km für das Display
int tankinhalt_ml_akt = 0;         // Aktueller Tankinhalt
int oilsymbol_Aus = 0;             // Variable für die Berechnung für das Anzeigenzeit des Ölsymbol
float gefahrene_m = 0;             // Berechnete Strecke in Meter. Wird zum Berechnen der Ölabstände benötigt
float Gefahrene_km = 0;            // Für die Anzeige der gefahrenen Strecke
float geschwindigkeit = 0;         // Aktuelle Geschwindigkeit
float Next_Loop = 0;               // Wird im LOOP zur steuerung benötigt
float variable_pumpe_ein = 0;      // Variable zum steuern der Pumpe
float variable_pumpe_pause = 0;    // Variable zum steuern der Pumpe
float serial_data = 5000;          // Wird  zum erkenne der Seriellen Daten vom GPS benutzt
float pumpe_aus = 0;               // Variable zum steuern der Pumpe
float TimeAPoutmillis;             // Variable für die Abschaltung des AP
long Gefahrene_km_Ges = 10;        // Km Gesamt
long pump_anzahl_Ges = 0;          // Pumpimpulse Gesamt

// Speicheraddressen der Benutzerdifinierten Variablen
int addr_Factory_init = 0;                 // Wird für die Initiallisierung benötigt
int addr_anzahl_Pump = 50;                 // Adresse für Pumpanzahl
int addr_tankinhalt_ml = 100;              //
int addr_pumps_ml = 150;                   //
int addr_tankinhalt_ml_akt = 200;          //
int addr_pumpDistanz = 250;                // Abstand in m zwischen den einzelnen Ölungen
int addr_minGeschwindigkeit = 300;         // Mindestgeschwindigkeit zum Ölen
int addr_oilsymbol_Zeit = 350;             // Zeit des Ölsymbol in
int addr_tankinhalt_max = 400;             // Anzahl der Pumpimpulse die benötigt werden um den Tank zu leeren
int addr_geschwindigkeit_Notbetrieb = 450; // Geschwindigkeit die angenommen wird wenn kein Sat-Empfang ist (Notbetrieb)
int addr_zeit_bis_notbetrieb = 500;        // Zeit bis Notbetrieb in ms
int addr_zeit_pumpe_ein = 550;             // Zeit in ms wie lage die Pumpe eineschaltet ist
int addr_zeit_pumpe_pause = 600;           // Zeit zwischen den einzelnen Pumpimpulsen
int addr_sw_Regensensor_ein = 650;         //
int addr_sw_Regensensor_aus = 700;         //
int addr_regenmodus = 750;                 //
int addr_rainMulti = 800;                  //
int addr_TimeAPout = 850;                  // Zeit bis zum abschalter des AP
int addr_init_pump_anzahl = 900;           //
int addr_gefahrene_m = 1100;               // Wird zur Berechnung der Zurückgelegten entfernung benötigt
int addr_Start_disp_1 = 1150;              //
int addr_Start_disp_2 = 1200;              //
int addr_pump_nach_Regen = 1350;           // Pumpimpulse wenn der Regenmodus abgeschaltet wird
int addr_ssid_ap = 1500;                   // Name des AP
int addr_password_ap = 1800;               // Password AP
int addr_Gefahrene_km = 2000;              //
int addr_Gefahrene_km_Ges = 2100;          //
int addr_Gefahrene_km_Display = 2200;      //
int addr_tankinhalt_Aktuell = 2300;        //
int addr_pump_anzahl_Ges = 2400;           //
int addr_dir_Display = 2500;               //

// Variablen für die Umwandlung in char in void update_Display ()
char stringSpeed[10];                // Create a character array of 10 characters
char stringDir[10];                  // Create a character array of 10 characters
char stringGefahrene_km_display[10]; // Create a character array of 10 characters
char stringsateliten_anzahl[10];     // Create a character array of 10 characters
char StringFaktor[10];               // Create a character array of 10 characters
char stringMittelwert[10];           // Create a character array of 10 characters

// WiFi
byte my_WiFi_Mode = 2;              // WIFI_STA = 1 = Workstation  WIFI_AP = 2  = Accesspoint
IPAddress local_ip(192, 168, 4, 1); // Die Festgelegte IP Adresse des AP

WiFiServer server(80);
WiFiClient client;

#define MAX_PACKAGE_SIZE 2048
char HTML_String[5000];
char HTTP_Header[150];

#define ACTION_SET_WIFI 1
#define ACTION_SET_OILEN 2
#define ACTION_SET_TANK 3
#define ACTION_SET_PAGE 4
#define ACTION_SET_NOTBETRIEB 5
#define ACTION_SET_PUMPE 6
#define ACTION_SET_ANZEIGEZEIT_DISP 7
#define ACTION_SET_TANK_RESET 8
#define ACTION_LIES_AUSWAHL 9
#define ACTION_LIES_VOLUME 10
#define ACTION_SET_DATE_TIME 11
#define ACTION_SET_SPUELEN_EIN 12
#define ACTION_SET_SPUELEN_AUS 13
#define ACTION_SET_OILSYMBOL_Zeit 14
#define ACTION_SET_REGENMODUS 15
#define ACTION_SET_APaus 18
#define ACTION_SET_EXTRAOILEN_EIN 19
#define ACTION_SET_EXTRAOILEN_AUS 20
#define ACTION_SET_ACTION_SET_INIT_PUMP 21

char tmp_string[20];

unsigned long ulReqcount;

// Auflistung der Funktionen
int read_int(int address);
void update_km();
void update_Oelen();
void update_GPS_Data();
void update_Display();
void Oelen();
void update_Rain();
void start_Disp_1();
void start_Disp_2();
void set_Eeprom();
void reed_Eeprom();
void WiFi_Start_AP();
void write_char_array(int address, char *value, int length, int i2c_address);
void read_char_array(int address, int length, int i2c_address, char *rcvData);
void write_int(int address, unsigned int value);
void set_Faktory();
void AP_Set_Faktory();
void WiFI_Traffic();
void Status_Serial();
long read_long(int address);
void write_long(int address, long value);
void strcatf(char *tx, float i);
void oled_start();

// WIFI
int Pick_Parameter_Zahl(const char *par, char *str);
int Find_Start(const char *such, const char *str);
int Find_End(const char *such, const char *str);
int Pick_Dec(const char *tx, int idx);
int Pick_N_Zahl(const char *tx, char separator, byte n);
void set_colgroup1(int ww);
void make_HTML01();
void make_HTML02();
void send_not_found();
void strcati(char *tx, int i);
void send_HTML();
void exhibit(const char *tx, int v);
void Pick_Text(char *tx_ziel, char *tx_quelle, int max_ziel);
void set_colgroup(int w1, int w2, int w3, int w4, int w5);
void strcati2(char *tx, int i);
char HexChar_to_NumChar(char c);

// Hier ist das Symbol der Ölkanne
static const unsigned char PROGMEM oilcan[] =
    {
        B00110000,
        B00000000,
        B01001100,
        B00000000,
        B10011011,
        B00000000,
        B10110011,
        B00000000,
        B01100001,
        B10000000,
        B11000000,
        B11100000,
        B01100000,
        B00011100,
        B00110000,
        B00000110,
        B00011000,
        B01111110,
        B00001100,
        B11000000,
        B00000111,
        B10000000,
        B00000000,
        B00000100,
        B00000000,
        B00001110,
        B00000000,
        B00011111,
        B00000000,
        B00011111,
        B00000000,
        B00001100,
};
// Hier ist das Symbol für Satelitenempfang
static const unsigned char PROGMEM satelite[] =
    {
        B00000000,
        B01110000,
        B01000011,
        B10110000,
        B00101100,
        B00111000,
        B00011000,
        B00101000,
        B00011000,
        B01001000,
        B00100100,
        B01001000,
        B01000010,
        B10001000,
        B01000001,
        B00001000,
        B10000010,
        B00010000,
        B10000100,
        B00110000,
        B01110000,
        B00110000,
        B01100000,
        B01111000,
        B00011111,
        B11111100,
        B00000001,
        B11111110,
        B00000001,
        B11111111,
        B00000001,
        B11111111,

};
// Hier ist das Symbol für Regen
static const unsigned char PROGMEM raining[] =
    {
        B00000011,
        B10000000,
        B00001100,
        B01100000,
        B00111000,
        B00111100,
        B01000000,
        B01000010,
        B01000000,
        B10000010,
        B01000000,
        B00000110,
        B00100000,
        B00000100,
        B00011100,
        B00111000,
        B00000111,
        B11100000,
        B00010000,
        B10001000,
        B00001000,
        B01000100,
        B00000100,
        B00000010,
        B00000000,
        B00010000,
        B00001001,
        B00001000,
        B00000100,
        B10000100,
        B00000010,
        B01000010,
};

// Serielle Eingaben
void evaluate(String input)
{
  // Pumpzeit
  if (input.startsWith(Vari_zeit_pumpe_ein))
  {
    input.replace(Vari_zeit_pumpe_ein, "");
    int value = input.toInt();
    Serial.print(Vari_zeit_pumpe_ein);
    Serial.println(value);
    zeit_pumpe_ein = value;
    write_int(addr_zeit_pumpe_ein, zeit_pumpe_ein);
  }
  // Pumppause
  else if (input.startsWith(Vari_zeit_pumpe_pause))
  {
    input.replace(Vari_zeit_pumpe_pause, "");
    int value = input.toInt();
    Serial.print(Vari_zeit_pumpe_pause);
    Serial.println(value);
    zeit_pumpe_pause = value;
    write_int(addr_zeit_pumpe_pause, zeit_pumpe_pause);
  }
  // Ölsymbol Anzeigezeit
  else if (input.startsWith(Vari_oilsymbol_Zeit))
  {
    input.replace(Vari_oilsymbol_Zeit, "");
    int value = input.toInt();
    Serial.print(Vari_oilsymbol_Zeit);
    Serial.println(value);
    oilsymbol_Zeit = value;
    write_int(addr_oilsymbol_Zeit, oilsymbol_Zeit);
  }
  // Zeit bis Notbetrieb
  else if (input.startsWith(Vari_zeit_bis_notbetrieb))
  {
    input.replace(Vari_zeit_bis_notbetrieb, "");
    int value = input.toInt();
    Serial.print(Vari_zeit_bis_notbetrieb);
    Serial.println(value);
    zeit_bis_notbetrieb = value;
    write_int(addr_zeit_bis_notbetrieb, zeit_bis_notbetrieb);
  }
  // Geschwindigkeit Notbetrieb
  else if (input.startsWith(Vari_Not_geschwindigkeit))
  {
    input.replace(Vari_Not_geschwindigkeit, "");
    int value = input.toInt();
    Serial.print(Vari_Not_geschwindigkeit);
    Serial.println(value);
    geschwindigkeit_Notbetrieb = value;
    write_int(addr_geschwindigkeit_Notbetrieb, geschwindigkeit_Notbetrieb);
  }
  // Pumpimpulse nach Regenmodus
  else if (input.startsWith(Vari_pump_nach_Regen))
  {
    input.replace(Vari_pump_nach_Regen, "");
    int value = input.toInt();
    Serial.print(Vari_pump_nach_Regen);
    Serial.println(value);
    pump_nach_Regen = value;
    write_int(addr_pump_nach_Regen, pump_nach_Regen);
  }
  // Pumpimpulse
  else if (input.startsWith(Vari_anzahl_Pump))
  {
    input.replace(Vari_anzahl_Pump, "");
    int value = input.toInt();
    Serial.print(Vari_anzahl_Pump);
    Serial.println(value);
    anzahl_Pump = value;
    write_int(addr_anzahl_Pump, anzahl_Pump);
  }
  // Min Gescchwindigkeit
  else if (input.startsWith(Vari_minGeschwindigkeit))
  {
    input.replace(Vari_minGeschwindigkeit, "");
    int value = input.toInt();
    Serial.print(Vari_minGeschwindigkeit);
    Serial.println(value);
    minGeschwindigkeit = value;
    write_int(addr_minGeschwindigkeit, minGeschwindigkeit);
  }
  // Gefahrene Km
  else if (input.startsWith(Vari_Gefahrene_km))
  {
    input.replace(Vari_Gefahrene_km, "");
    long value = input.toInt();
    Serial.print(Vari_Gefahrene_km);
    Serial.println(value);
    Gefahrene_km = value;
    write_long(addr_Gefahrene_km, Gefahrene_km);
  }
  // Gesamt Km
  else if (input.startsWith(Vari_Gefahrene_km_Ges))
  {
    input.replace(Vari_Gefahrene_km_Ges, "");
    long value = input.toInt();
    Serial.print(Vari_Gefahrene_km_Ges);
    Serial.println(value);
    Gefahrene_km_Ges = value;
    write_long(addr_Gefahrene_km_Ges, Gefahrene_km_Ges);
  }
  // Pumpdistanz
  else if (input.startsWith(Vari_pumpDistanz))
  {
    input.replace(Vari_pumpDistanz, "");
    int value = input.toInt();
    Serial.print(Vari_pumpDistanz);
    Serial.println(value);
    pumpDistanz = value;
    write_int(addr_pumpDistanz, pumpDistanz);
  }
  // Maximaler Tankinhalt
  else if (input.startsWith(Vari_tankinhalt_max))
  {
    input.replace(Vari_tankinhalt_max, "");
    int value = input.toInt();
    Serial.print(Vari_tankinhalt_max);
    Serial.println(value);
    tankinhalt_max = value;
    write_int(addr_tankinhalt_max, tankinhalt_max);
  }
  // Startdisplay 1
  else if (input.startsWith(Vari_Start_disp_1))
  {
    input.replace(Vari_Start_disp_1, "");
    int value = input.toInt();
    Serial.print(Vari_Start_disp_1);
    Serial.println(value);
    Start_disp_1 = value;
    write_int(addr_Start_disp_1, Start_disp_1);
  }
  // Startdisplay 2
  else if (input.startsWith(Vari_Start_disp_2))
  {
    input.replace(Vari_Start_disp_2, "");
    int value = input.toInt();
    Serial.print(Vari_Start_disp_2);
    Serial.println(value);
    Start_disp_2 = value;
    write_int(addr_Start_disp_2, Start_disp_2);
  }
  // Pumpimpulse Gesamt
  else if (input.startsWith(Vari_pump_anzahl_Ges))
  {
    input.replace(Vari_pump_anzahl_Ges, "");
    int value = input.toInt();
    Serial.print(Vari_pump_anzahl_Ges);
    Serial.println(value);
    pump_anzahl_Ges = value;
    write_int(addr_pump_anzahl_Ges, pump_anzahl_Ges);
  }
  // Geschwindigkeit
  else if (input.startsWith(Vari_geschwindigkeit))
  {
    input.replace(Vari_geschwindigkeit, "");
    int value = input.toInt();
    Serial.print(Vari_geschwindigkeit);
    Serial.println(value);
    geschwindigkeit = value;
    // write_int(addr_pump_anzahl_Ges, pump_anzahl_Ges);
  }
  // RainMulti
  else if (input.startsWith(Vari_rainMulti))
  {
    input.replace(Vari_rainMulti, "");
    int value = input.toInt();
    Serial.print(Vari_rainMulti);
    if (value <= 1)
    {
      value = 1;
    }
    Serial.println(value);
    rainMulti = value;
    write_long(addr_rainMulti, rainMulti);
  }
  // Status Ausrufen
  else if (input.startsWith("Status"))
  {
    Status_Serial();
  }
  // Faktory Set
  else if (input.startsWith("Set_Factory"))
  {
    set_Faktory();
    Status_Serial();
  }
  // EEPROM INIT
  else if (input.startsWith("EEPROM_init"))
  {
    write_int(addr_Factory_init, 1);
    ESP.restart();
  }
}

void serialEvent()
{
  while (Serial.available())
  {
    // get the new byte:
    char inChar = (char)Serial.read();

    // if the incoming character is a newline, set a flag so the main loop can
    // do something about it:
    if (inChar == '\n')
    {
      // Serial.println(inputString);
      evaluate(inputString);
      // clear the string:
      inputString = "";
    }
    else
    {
      // add it to the inputString:
      inputString += inChar;
    }
  }
}
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
void loop()
{
  if (GPS_serial.available() > 0)
  {
    serial_data++;
  }

  while (GPS_serial.available() > 0)
    gps.encode(GPS_serial.read());

  if (millis() >= Next_Loop)
  {
    Next_Loop = (millis() + 1000);
    update_GPS_Data();
    update_km();
    update_Rain();
    update_Oelen();

    if (oled_akt == false)
    {
      update_Display();
    }
  }

  if (oilen || Spuelen)
  {
    if (Spuelen)
    {
      pump_anzahl_soll = 1;
      Oelen();
    }

    if (geschwindigkeit >= minGeschwindigkeit)
    {
      Oelen();
    }
  }

  if (digitalRead(Wlan_Reset) == LOW)
  {
    AP_Set_Faktory();
  }

  if (millis() >= TimeAPoutmillis)
  {
    WiFi.mode(WIFI_OFF);
    TimeAPout_set = true;
  }

  if (TimeAPout_set == false)
  {
    WiFI_Traffic();
  }
}

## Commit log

2023-06-10 Dateien eingefügt
    [Distanzscheibe_unten.dxf, GPS-Gehaeuse.stl, GPS-Gehaeuse_Deckel.stl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]
2023-08-20 An der Beschreibung gearbeitet
2023-08-30 Beschreibung geändert
    [Distanzscheibe_unten.dxf, GPS-Gehaeuse.stl, GPS-Gehaeuse_Deckel.stl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]
